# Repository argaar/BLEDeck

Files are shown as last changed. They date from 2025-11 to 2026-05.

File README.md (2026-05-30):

# BLEDeck



A custom BLE macro pad controlled by a Windows desktop application. Press a key, run a command. Switch profile, change context. Everything is driven by the app, the device is a pure peripheral.

<p align="center">
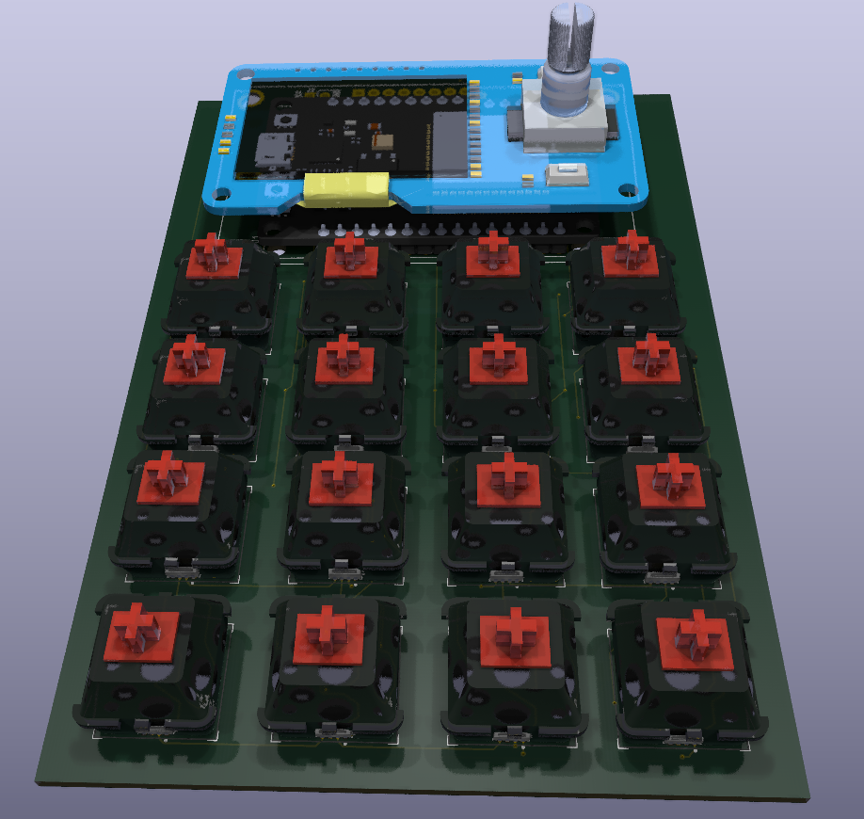
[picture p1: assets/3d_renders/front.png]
BLEDeck front render
  
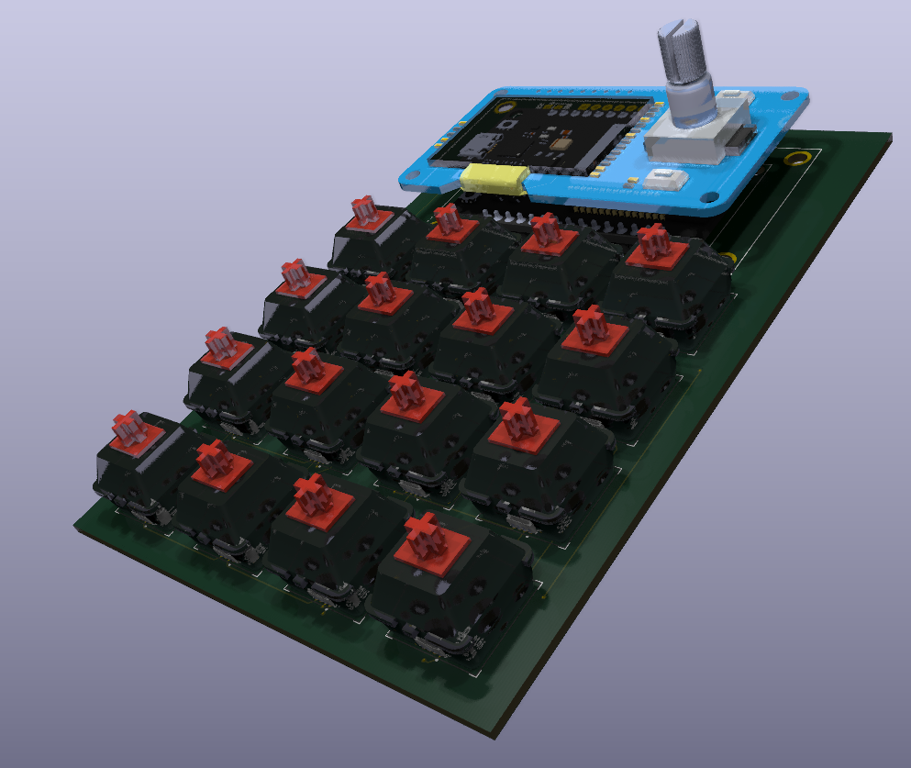
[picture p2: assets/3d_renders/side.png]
BLEDeck side render
  
</p>

---

## Overview

BLEDeck is a 4×4 mechanical keypad with per-key RGB lighting, a rotary encoder, and an OLED display, built around an ESP32. It communicates over BLE with a Windows app that maps each key to a shell command or executable. Profiles let you maintain separate key layouts for different workflows.

The device carries no persistent state. Every time the app connects, it pushes the current profile names and key colors to the device. This is by design, the app is the source of truth.

---

## Hardware

| Component | Part |
|---|---|
| MCU | ESP32 DevKitC v1 (NodeMCU-32S) |
| Keys | 16 × Gateron switches (CherryMX style) on Kailh hot-swap sockets |
| RGB | 16 × WS2812B-4020 side-emitting SMD LEDs |
| Display | SSD1306 128×64 OLED |
| Encoder | EC11 rotary encoder with push button |
| Extra buttons | CON (confirm) + BACK, mounted beside the encoder |
| Battery | Optional 1S LiPo with 15 kΩ / 4.3 kΩ voltage divider on GPIO 13 |
| PCB | Custom KiCad design, v1.1 (files under `pcb/`) |

<p align="center">
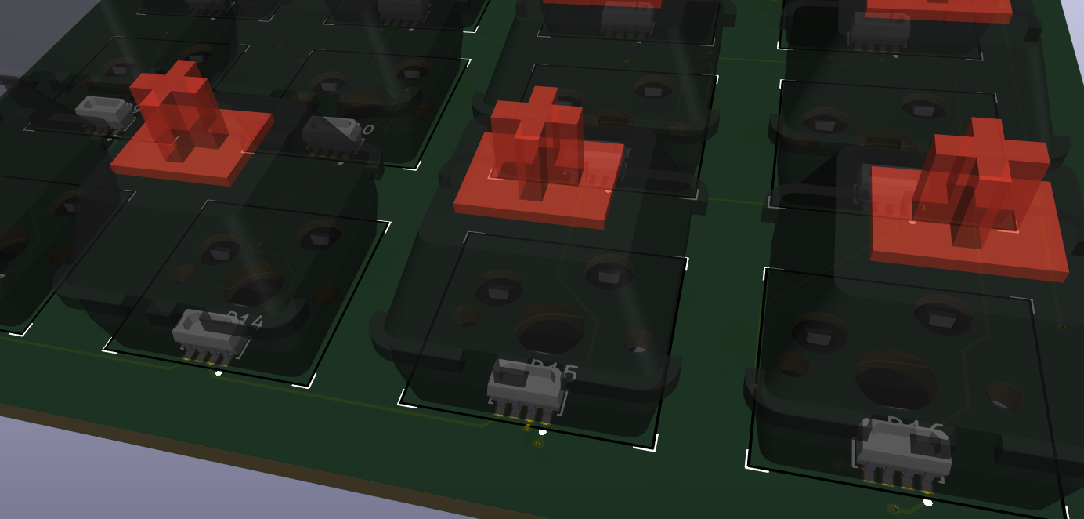
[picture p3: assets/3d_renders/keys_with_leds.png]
Keys with per-key RGB LEDs
  
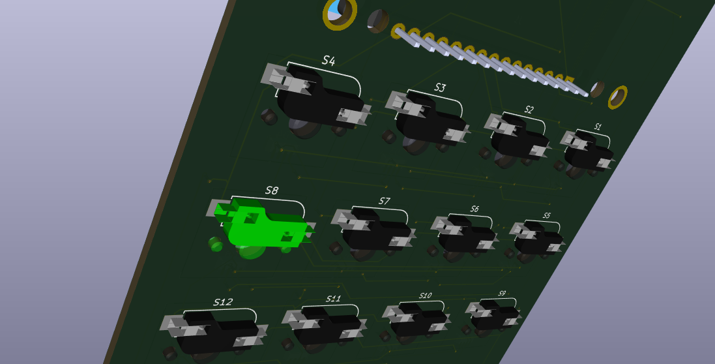
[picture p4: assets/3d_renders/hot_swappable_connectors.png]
Hot-swappable switch connectors
  
</p>

---

## Repository Layout

```
BLEDeck/
├── firmware/          PlatformIO project (ESP32 Arduino)
│   └── src/
│       ├── main.cpp            Main loop, BLE callbacks, all handlers
│       ├── configuration.h     Pin map, BLE limits, battery constants
│       ├── protocolparser.h    Binary protocol definition + packet parser
│       ├── ota_manager.h/.cpp  WiFi OTA update manager (ElegantOTA)
│       ├── menu.h              Simple OLED settings menu
│       ├── images.h            XBM splash/lock screen bitmaps
│       └── credentials.h       WiFi + OTA password (gitignored, see below)
├── windows_app/       PyQt5 desktop application
│   ├── main.py                 BLEDeck GUI, BLE lifecycle, notification dispatch
│   ├── key_button.py           KeyButton widget
│   ├── ble_protocol.py         Packet builders, parsers, opcode constants
│   ├── ble_client.py           BleakClient re-export, BLE UUIDs, simulator factory
│   ├── profile_manager.py      Load/save profiles.json
│   ├── app_settings.py         Persistent app-level settings (preferred device MAC, …)
│   ├── action_runner.py        Command/macro dispatch with re-entrancy guard
│   ├── macro_models.py         Immutable step types + JSON serialization
│   ├── macro_recorder.py       pynput-based recorder with window anchor detection
│   ├── macro_player.py         Synchronous macro playback
│   ├── macro_dialog.py         MacroDialog QDialog (record, edit, reorder, test)
│   ├── win32_utils.py          Windows API helpers (window/monitor detection)
│   └── tests/                  Pytest suite
│       ├── test_ble_protocol.py
│       ├── test_profile_manager.py
│       ├── test_action_runner.py
│       └── test_macro_models.py
├── simulator/         BLE device simulator (no hardware needed)
│   ├── __main__.py             Entry point: python -m simulator [--ble]
│   ├── _context.py             Module-level singletons (DeviceState, active client)
│   ├── device_state.py         Simulated device state
│   ├── command_handler.py      PC→Device command handler
│   ├── event_emitter.py        Device→PC event builders
│   ├── ble_server.py           Real BLE via WinRT GattServiceProvider (Mode B)
│   ├── fake_bleak_client.py    In-process loopback (Mode A)
│   ├── cli.py                  Interactive REPL
│   └── tests/                  Pytest suite
├── pcb/               KiCad schematic + layout + Gerbers
├── docs/              Protocol reference and debugging guides
│   ├── ble_protocol_reference.md
│   ├── protocol_debugging.md
│   └── hex_quick_reference.md
└── debug/
    └── protocol_decoder.py     CLI tool to decode raw BLE packets
```

---

## Firmware

Full setup and configuration details: [`firmware/README.md`](firmware/README.md)

### Features

- **BLE GATT server** - custom service with a TX (notify) and RX (write) characteristic
- **Binary protocol** - compact framed packets: `0xAA | OPCODE | LENGTH(2B) | PAYLOAD`; max payload 256 bytes
- **Profile management** - up to 10 profiles; names and current index are pushed by the app on connect
- **Rotary encoder** - cycles through profiles when the app is connected; plays an idle RGB animation when disconnected
- **Per-key RGB** - 16 WS2812B LEDs, colors set individually or all at once by the app
- **OLED display** - shows current profile name, BLE connection status, and battery percentage
- **Battery monitoring** - ADC reading every 30 s, 5-sample rolling average, reported to the app via opcode `0x85`
- **Workstation lock** - when locked by the app, the OLED dims and shows a lock icon; all key events are suppressed
- **OTA updates** - long-press the encoder push button to open the settings menu, select *OTA Update*; the device connects to WiFi (or falls back to an AP) and serves the ElegantOTA web UI
- **`OP_HELLO` / `OP_DEVICE_TELEMETRY` handshake** - on connect the app sends `OP_HELLO` with its protocol/app version, the device replies with telemetry (firmware version, uptime, free heap, BLE error count)
- **OTA HTTP auth rate-limit infrastructure** - 5 failed logins within 60 s trigger a 5-minute lockout (trigger awaits an ElegantOTA upstream hook)

### Firmware Setup

1. Install [PlatformIO](https://platformio.org/).
2. Copy `firmware/src/credentials.h.example` → `firmware/src/credentials.h` and fill in:
   ```cpp
   #define OTA_WIFI_SSID     "your_ssid"
   #define OTA_WIFI_PASSWORD "your_wifi_password"
   #define OTA_HTTP_PASSWORD "your_ota_http_password"
   ```
3. Build and flash:
   ```bash
   cd firmware
   pio run --target upload
   ```

### Build a personalized firmware via GitHub Actions (no toolchain)

Don't want to install PlatformIO? You can have GitHub build a firmware binary
with **your own** WiFi + OTA credentials baked in and email it to you. The
`Build Personalized Firmware` workflow handles it.

1. **Fork** this repository to your own GitHub account (Actions and secrets run
   under your fork, not the upstream repo).
2. In your fork, add two repository secrets under
   **Settings → Secrets and variables → Actions → New repository secret**:
   - `MAIL_USERNAME` — the Gmail address that sends the build
   - `MAIL_PASSWORD` — a Gmail [App Password](https://support.google.com/accounts/answer/185833)
     for that account (requires 2-Step Verification; your normal password will
     not work)
3. Open the **Actions** tab → **Build Personalized Firmware** →
   **Run workflow**, and fill in:
   - `wifi_ssid`, `wifi_password` — the network the device joins for OTA
   - `ota_http_password` — the password for the OTA upload page
   - `recipient_email` — where to send the finished `firmware.bin`
4. Wait for the run to finish (a few minutes). The compiled `firmware.bin`
   arrives by email; flash it to the ESP32 with ElegantOTA or `esptool`.

> **Spam note:** the email is sent from a personal Gmail account with an
> attachment, so it can land in **Spam/Junk**. If it doesn't show up in your
> inbox within a few minutes, check there and mark it *Not spam*.

> **Privacy note:** the credentials you enter are masked in the build logs and
> the generated `credentials.h` is deleted at the end of the run, but the
> finished binary still contains them and travels through Gmail. Use this for
> personal networks, not shared/sensitive ones.

---

## Windows App

Full setup and usage details: [`windows_app/README.md`](windows_app/README.md)

### Features

- Scan and connect to BLEDeck over BLE (auto-reconnect optional)
- **Per-key configuration** - label, RGBW color (with color picker + brightness slider), action
- **Two action types per key** - shell command (via `subprocess`) or recorded macro
- **Macro recorder** - capture mouse clicks and keystrokes; replay them on key press
  - Per-click window/monitor-relative coordinates: clicks are anchored to the window or monitor they were recorded on, so playback works even if windows have moved
  - Multi-monitor support: monitors indexed by left edge (0 = leftmost)
  - Edit individual steps, drag-to-reorder, delete steps, test-run from the dialog
- **Profile management** - create, rename, save, and delete profiles; stored in `profiles.json`
- **Live RGB sync** - changing a key color sends the update to the device immediately
- **Battery indicator** - displays the battery percentage reported by the device
- **System tray** - minimises to tray, double-click or single-click to restore
- On connect: pushes all profile names, then the current profile index + RGB colors
- **Rotating debug log** at `%APPDATA%\BLEDeck\logs\bledeck.log` (5 × 20 MB rotation, 100 MB cap; KEEP_ALIVE traffic filtered out)
- **Preferred device MAC pinning** + **exponential reconnect backoff** (10 s → doubles per failed attempt → 5 min cap; resets on success)
- **High-risk command-token warning** on profile load — flags commands containing tokens such as `powershell`, `cmd /c`, `iex`, `curl … | iex`, `bitsadmin`, `mshta` before they can run
- **Macro recorder auto-stop** after 60 s of idle keyboard / mouse activity

### App Setup

```bash
cd windows_app
pip install -r requirements.txt
python main.py
```

> Python 3.12 or later required. Tested on Windows 11.

### Development Without Hardware

A device simulator is included — no physical BLEDeck required.

Loopback mode (default): no Bluetooth, instant connect. Pick the row for your shell:

| Shell | Command |
|---|---|
| cmd.exe | `set BLEDECK_SIM=1 && python windows_app\main.py` |
| PowerShell  | `$env:BLEDECK_SIM=1; python windows_app\main.py` |
| Git Bash | `BLEDECK_SIM=1 python windows_app/main.py` |

Real BLE mode (two machines): simulator on Machine A, app on Machine B:

```bash
python -m simulator --ble
```

Full details: [`simulator/README.md`](simulator/README.md)

---

## BLE Protocol

Full reference: [`docs/ble_protocol_reference.md`](docs/ble_protocol_reference.md)

| Direction | Opcodes |
|---|---|
| PC → Device | `0x01` KEEP_ALIVE, `0x02` CHANGE_PROFILE, `0x03` SYNC_PROFILES, `0x04` SET_RGB_KEY, `0x05` SET_ALL_RGB_KEYS, `0x06` LOCK_DEVICE, `0x07` HELLO |
| Device → PC | `0x81` KEEP_ALIVE_REPLY, `0x82` PROFILE_CHANGED, `0x83` BUTTON_PRESSED, `0x84` KEY_PRESSED, `0x85` BATTERY_STATUS, `0x86` DEVICE_TELEMETRY |

To decode a raw packet from the log:
```bash
cd debug
python protocol_decoder.py "aa 85 00 01 48"
# or interactive:
python protocol_decoder.py
```

For advanced debugging see [`docs/protocol_debugging.md`](docs/protocol_debugging.md)
If you're interested in understanding the protocol, take a look at [`docs/hex_quick_reference.md`](docs/hex_quick_reference.md)

---

## Intended Use

BLEDeck is designed for Windows power users who want a physical shortcut pad without writing firmware macros. Key assignments live entirely in the app, change them without reflashing.

Typical profiles:
- **Dev** - open IDE, terminal, browser, run build script
- **Media** - control Spotify, OBS, volume
- **Gaming** - push-to-talk, clips, Discord mute
- **Comms** - join meeting, mute mic, share screen

The rotary encoder switches between profiles. The three encoder-side buttons (CON, BACK, PUSH) send named button events to the app, which can be mapped to any action.

---

## Limitations

- **Windows only** - the desktop app uses PyQt5, bleak, and ctypes Win32 APIs; no macOS or Linux app exists yet
- **App required** - the device does not persist colors or profile names; it resets to defaults when the app disconnects. This is intentional
- **10 profiles max, 16 keys per profile**
- **BLE range** - approximately 10 m in open space; walls reduce this
- **Battery gauge accuracy** - ±5%, based on a two-resistor voltage divider and a 5-sample average; calibrated for 1S LiPo (3.2 V – 4.2 V)
- **Macro recorder captures press events only** - release timing and mouse movement paths are not recorded

---

## PCB

Custom two-layer board designed in KiCad. Gerbers for JLCPCB are included under `pcb/`. Parts list and supplier links are in [`pcb/README.md`](pcb/README.md).

Current version: **v1.1**

---

## STLs

3D Models ready to be printed in PLA are available under `enclosure/stls` folder.

Ideally you need to assemble parts in the order:

- [PushButton.stl](enclosure/stls/PushButton.stl) (x2)
- [KeyboardLayer.stl](enclosure/stls/KeyboardLayer.stl)
- [BatteryTop.stl](enclosure/stls/BatteryTop.stl)
- [BatteryLayer.stl](enclosure/stls/BatteryLayer.stl)
- [Bottom.stl](enclosure/stls/Bottom.stl)

---

## License

Firmware and application source code are licensed under the [MIT License](LICENSE).

Hardware design files (PCB, schematics) and third-party component symbols/footprints retain their original licenses as listed in [`pcb/README.md`](pcb/README.md). The custom `oledknob.step` footprint is non-commercial use only.

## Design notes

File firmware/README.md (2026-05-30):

# BLEDeck Firmware

**Version: 1.2.5** — see [`src/version.h`](src/version.h)

ESP32 firmware for the BLEDeck macro pad. Built with PlatformIO and the Arduino framework. Acts as a BLE GATT peripheral - all logic and configuration are driven by the [Windows app](../windows_app/).

---

## Requirements

- [PlatformIO](https://platformio.org/) (CLI or VS Code extension)
- Board: **ESP32 DevKitC v1 / NodeMCU-32S**

---

## Setup

### 1. Create credentials file

The OTA credentials are not committed. Copy the example and fill it in:

```bash
cp src/credentials.h.example src/credentials.h
```

Edit `src/credentials.h`:

```cpp
#define OTA_WIFI_SSID     "your_wifi_ssid"
#define OTA_WIFI_PASSWORD "your_wifi_password"
#define OTA_HTTP_PASSWORD "your_ota_http_password"
```

### 2. Build and flash

```bash
pio run --target upload
```

Monitor serial output (115200 baud):

```bash
pio device monitor
```

### Optional build environments

`platformio.ini` defines two extra environments for diagnostics:

| Environment | Flag set | Purpose |
|---|---|---|
| `env:debug` | `-DDEBUG_SERIAL=1` | Verbose serial logging — prints every RX/TX packet, button presses, RGB updates. Default builds keep non-error prints silent. |
| `env:calibrate` | `-DCALIBRATE_BATTERY=1` | Battery-divider calibration mode. Sampling drops to every 5 s and the firmware prints both the current `BAT_CALIBRATION` value and the formula needed to retune it against a multimeter reading. |

Examples:

```bash
pio run -e debug --target upload          # Verbose logging build
pio run -e calibrate --target upload      # Calibration build
pio device monitor                        # Read the serial log
```

Switch back to the default environment by running `pio run --target upload` (or `pio run -e nodemcu-32 --target upload`).

### Native unit tests

Pure-host tests for the protocol parser and OTA rate-limit logic run on
PlatformIO's `native` env (Unity framework, no ESP32 required):

**Prerequisite:** A host C/C++ compiler. PlatformIO bundles only the
xtensa-esp32 toolchain — it does not ship a host gcc. Install one of:

| OS | Option |
|----|---|
| Windows | [w64devkit](https://github.com/skeeto/w64devkit/releases) (~80 MB zip; extract, add `bin/` to PATH) — lightest |
| Windows | `scoop install gcc` or `choco install mingw` |
| Linux | usually pre-installed; otherwise `sudo apt install build-essential` (or distro equivalent) |
| macOS | `xcode-select --install` |

Verify with `gcc --version` before running the command below.

```bash
pio test -e native
```

Tests live under `firmware/test/`. Add new native tests as
`test/<test_name>/test_main.cpp` — PlatformIO discovers each subdirectory
automatically.

---

## Pin Map

| Function | GPIO |
|---|---|
| OLED SDA | 21 |
| OLED SCL | 22 |
| Encoder A | 35 |
| Encoder B | 34 |
| Button CON | 36 |
| Button BACK | 39 |
| Button PUSH | 27 |
| Keypad rows | 32, 33, 25, 26 |
| Keypad cols | 5, 18, 19, 23 |
| RGB data | 14 |
| Battery ADC | 13 |

**Power & ground:** OLED VCC = 3.3 V. Encoder PUSH input (GPIO 27) is wired to the EC11 SW pin and shares the encoder common GND.

---

## Features

### BLE
- GATT server advertising as `BLEDeck`
- Custom service UUID `4FAFC201-...`
- TX characteristic (notify) for device → app events
- RX characteristic (write) for app → device commands
- TX power set to maximum (+9 dBm) for range
- Auto-restarts advertising on disconnect

### Keypad
- 4×4 matrix, keys labelled `0`–`9`, `A`–`F`
- Each keypress sends `OP_KEY_PRESSED` with the current profile index and key character

### Rotary encoder + buttons
- Turning the encoder cycles through profiles (wraps around)
- **CON** and **BACK** send `OP_BUTTON_PRESSED` with the button name
- **PUSH** short-press sends `OP_BUTTON_PRESSED`
- **PUSH** long-press (≥ 1500 ms) opens the settings menu

### RGB LEDs
- 16 × WS2812B-4020 controlled via NeoPixelBus
- App sets colors per-key (`OP_SET_RGB_KEY`) or all at once (`OP_SET_ALL_RGB_KEYS`)
- Idle animation (rotating rainbow) plays when no app is connected
- Colors reset to defaults on disconnect - the app re-applies them on every connect

### OLED display
- Shows current profile name, BLE connection status, and battery percentage
- Displays a lock icon when the workstation is locked

### Battery monitoring
- ADC reading on GPIO 13 every 30 s (5-sample rolling average)
- Voltage divider: 15 kΩ (top) / 4.3 kΩ (bottom), calibrated for 1S LiPo (3.2 V – 4.2 V). `BAT_R1 = 15000` and `BAT_R2 = 4300` in `configuration.h` match the soldered PCB (the schematic Value fields are wrong — trust the constants, not the schematic).
- Reports percentage to the app via `OP_BATTERY_STATUS (0x85)` immediately on connect and after each reading
- `0xFF` is sent when no battery is detected (USB-only)

#### Battery calibration

The easiest way to calibrate is to flash the `env:calibrate` build. It prints both the current `BAT_CALIBRATION` constant and the value you need to paste back into `configuration.h`, sampling every 5 seconds.

GPIO 13 is on ADC2, which over-reads versus the true input voltage. `BAT_CALIBRATION` in `configuration.h` (currently `0.3607`) absorbs that drift. To tune it on a specific board:

1. Connect over USB and open the serial monitor (115200 baud). The firmware now prints a battery line **unconditionally every 30 s**:
   ```
   [BAT] adc=XXXX mV  vbat=YYYY mV  pct=ZZ
   ```
2. Probe the battery terminals with a multimeter at the same moment and note the real voltage (e.g. `3987 mV`).
3. Recompute the constant:
   ```
   BAT_CALIBRATION_new = multimeter_mV / vbat_mV * BAT_CALIBRATION_current
   ```
   For example, if `vbat = 3700 mV`, multimeter reads `3987 mV` and current `BAT_CALIBRATION = 0.3607`:
   `0.3607 * (3987 / 3700) ≈ 0.3887`.
4. Update `BAT_CALIBRATION` in `configuration.h`, reflash, and verify. A two-point measurement (e.g. ~3.4 V and ~4.1 V) is enough for ±1 % accuracy across the full pack range.

### Workstation lock
- `OP_LOCK_DEVICE (0x06)` from the app locks/unlocks the device
- When locked: OLED dims, lock icon displayed, all key/encoder events suppressed

### OTA update
1. Long-press the PUSH button to open the settings menu
2. Select **OTA Update** - BLE is shut down, WiFi starts
3. Connect a browser to the device IP (or to `BLEDeck-OTA` AP if WiFi credentials fail). The AP fallback uses a **randomized 12-character password** printed on the OLED and over serial.
4. Log in to the ElegantOTA web interface using the `OTA_HTTP_PASSWORD` you set in `credentials.h` and upload a new `.bin`
5. Device restarts automatically. To cancel an in-progress OTA session, **hold BACK for at least 1000 ms** (a brief tap is ignored, so an accidental press doesn't abort a flash).
6. OTA session times out after 5 minutes if no upload is started

### Protocol handshake & telemetry

On every BLE connect, the app sends `OP_HELLO` (0x07) with its app version and the negotiated `PROTOCOL_VERSION`. The firmware replies with `OP_DEVICE_TELEMETRY` (0x86) carrying the firmware version, current uptime, last-reset reason (`esp_reset_reason()`), free heap, and a running BLE-error counter incremented on every malformed packet, send failure, or oversize payload. Mismatched protocol versions surface a CRITICAL warning in the app's log and a status-bar message.

### OTA rate-limit

The OTA HTTP endpoint tracks failed authentication attempts in a small ring buffer. **Five failures within 60 s trigger a 5-minute lockout**, during which all incoming HTTP traffic is dropped (`server_->handleClient()` is skipped). The lockout counter infrastructure is fully wired; ElegantOTA 3.1.7 does not currently expose an auth-failure callback, so the trigger awaits either an upstream hook or a future self-hosted route handler — see the TODO at the top of `OtaManager::loop()`.

### Task watchdog

The ESP32 Arduino framework feeds the IDLE task watchdog automatically as long as `loop()` returns within the configured timeout (default 5 s). BLE callbacks (`onConnect`, `onDisconnect`, RX characteristic write) run on the NimBLE host task — keep them to flag-flipping plus simple state updates; never call `delay()`, I²C, or SPI. OTA mode shuts BLE down before WiFi starts, so the BLE task is dormant during ElegantOTA serving. See the comment block above `setup()` in `main.cpp`.

---

## Source Files

| File | Purpose |
|---|---|
| `main.cpp` | Setup, main loop, BLE callbacks, all packet handlers |
| `configuration.h` | Pin definitions, BLE limits, battery constants |
| `protocolparser.h` | Protocol definition (all opcodes), binary packet parser |
| `ota_manager.h/.cpp` | WiFi connection, ElegantOTA lifecycle, AP fallback |
| `menu.h` | Minimal OLED scrollable menu |
| `images.h` | XBM bitmaps (splash screen, lock icon) |
| `version.h` | Firmware version constants (`FIRMWARE_VERSION`, `_MAJOR/_MINOR/_PATCH`) |
| `credentials.h` | WiFi SSID/password + OTA password (gitignored) |

---

## Configuration Constants (`configuration.h`)

| Constant | Default | Description |
|---|---|---|
| `MAX_BLE_PAYLOAD_LEN` | 256 | Parser hard limit (matches `MAX_PAYLOAD_LEN` in protocol) |
| `MENU_LONG_PRESS_MS` | 1500 | Hold duration to open settings menu |
| `OTA_TIMEOUT_MS` | 300 000 | OTA idle timeout before auto-restart (ms) |
| `BAT_INTERVAL_MS` | 30 000 | Battery ADC read interval (ms) |
| `BAT_MIN_V` | 3200 | Minimum LiPo voltage mapped to 0% (mV) |
| `BAT_MAX_V` | 4200 | Maximum LiPo voltage mapped to 100% (mV) |
| `BAT_NUM_READ` | 5 | Rolling average window for ADC readings |

To disable battery support entirely, comment out `#define USE_BATTERY` in `configuration.h`.

---

## Dependencies

| Library | Version | Purpose |
|---|---|---|
| chris--a/Keypad | ^3.1.1 | 4×4 matrix keypad scan |
| maffooclock/ESP32RotaryEncoder | ^1.1.2 | Interrupt-driven rotary encoder |
| thomasfredericks/Bounce2 | ^2.72 | Button debouncing |
| ThingPulse/esp8266-oled-ssd1306 | 4.6.1 | SSD1306 OLED driver |
| makuna/NeoPixelBus | ^2.8.4 | WS2812B RGB LED control |
| rlogiacco/CircularBuffer | ^1.4.0 | Rolling ADC average buffer |
| ayushsharma82/ElegantOTA | ^3.1.7 | Web-based OTA update UI |

---

## Protocol

See [`../docs/ble_protocol_reference.md`](../docs/ble_protocol_reference.md) for the full binary protocol specification.

Quick opcode reference:

| Opcode | Direction | Name |
|---|---|---|
| `0x01` | App → Device | KEEP_ALIVE |
| `0x02` | App → Device | CHANGE_PROFILE |
| `0x03` | App → Device | SYNC_PROFILES |
| `0x04` | App → Device | SET_RGB_KEY |
| `0x05` | App → Device | SET_ALL_RGB_KEYS |
| `0x06` | App → Device | LOCK_DEVICE |
| `0x07` | App → Device | HELLO |
| `0x81` | Device → App | KEEP_ALIVE_REPLY |
| `0x82` | Device → App | PROFILE_CHANGED |
| `0x83` | Device → App | BUTTON_PRESSED |
| `0x84` | Device → App | KEY_PRESSED |
| `0x85` | Device → App | BATTERY_STATUS |
| `0x86` | Device → App | DEVICE_TELEMETRY |

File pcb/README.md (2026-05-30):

# Parts list

### LED RGB WS2812b SMD 4020
https://jlcpcb.com/partdetail/Worldsemi-WS2812B4020/C965557

### Through Hole Resistor 2.2*6.5 250mW (15k + 4.3k)
Battery voltage divider on GPIO 13 (R1=15k top to BAT+, R2=4.3k bottom to GND).
https://jlcpcb.com/partdetail/59662-MFR0W4F1502A50/C58617
https://jlcpcb.com/partdetail/NTEElectronics-QW243/C6262373

### ESP32 DevKitC v1
https://lastminuteengineers.com/esp32-pinout-reference/
https://www.adrirobot.it/modulo-esp32-devkit-v1-con-wifi-e-bluetooth-ble/

### OLED (SSD1306) + Knob (EC11 rotary encoder)
https://it.aliexpress.com/item/1005009186762942.html

### Gateron Switches (CherryMX Style)
https://keychron.it/products/gateron-g-pro-3-0-switch?variant=51681846395247
https://it.aliexpress.com/item/1005006376024657.html

### Switch Transparent Cover
https://it.aliexpress.com/item/1005006821410180.html

### Kahil Hot swappable sockets
https://splitkb.com/products/kailh-hotswap-sockets
https://www.amazon.it/dp/B0DJKTNDHF
https://it.aliexpress.com/item/1005004654079817.html

### Adesive TPU Pads
https://it.aliexpress.com/item/1005006390636772.html

# Resources licenses

### Symbols

- ESP32-DEVKIT-V1.kicad_sym - https://www.snapeda.com/parts/ESP32-DEVKIT-V1/Do+it/view-part/ - CC-BY-SA
- PG151101S11.kicad_sym - https://www.snapeda.com/parts/PG151101S11/Kailh/view-part/ - CC-BY-SA
- WS2812B-4020.kicad_sym - https://www.snapeda.com/parts/WS2812B-4020/Worldsemi/view-part/ - CC-BY-SA

### Footprints

- MODULE_ESP32_DEVKIT_V1.kicad_mod - https://www.snapeda.com/parts/ESP32-DEVKIT-V1/Do+it/view-part/ - CC-BY-SA
- Kailh_socket_MX.kicad_mod - https://github.com/daprice/keyswitches.pretty - CC-BY-SA 4
- oled_rotary.kicad_mod - Custom Made under MIT License
- PinHeader_1x02_P2.54mm_Vertical.kicad_mod - https://gitlab.com/kicad/libraries/kicad-footprints/ - CC-BY-SA 4
- WS2812B-4020.kicad_mod - https://www.snapeda.com/parts/WS2812B-4020/Worldsemi/view-part/ - CC-BY-SA

### 3D Models

- CherryMX Switch.step - https://github.com/foostan/kbd - MIT
- ESP32-DEVKIT-V1.step - https://www.snapeda.com/parts/ESP32-DEVKIT-V1/Do+it/view-part/ - CC-BY-SA
- kailh_hotswap_socket.step - https://www.snapeda.com/parts/PG151101S11/Kailh/view-part/ - CC-BY-SA
- oledknob.step - https://grabcad.com/library/1-3-oled-ec11-1 - No commercial use
- WS2812B-4020--3DModel-STEP-269445.STEP - https://www.snapeda.com/parts/WS2812B-4020/Worldsemi/view-part/ - CC-BY-SA

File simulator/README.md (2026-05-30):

# BLEDeck Simulator

Software emulator for the BLEDeck hardware device. Lets developers work on the Windows app without owning a physical device.

Two modes:

| Mode | What it does | When to use |
|---|---|---|
| **Mode A — Loopback** (default) | In-process fake BLE client. No radio needed. | Daily development, CI, no Bluetooth hardware |
| **Mode B — Real BLE** (`--ble`) | Advertises via WinRT GattServiceProvider. App on a second machine connects normally. | Cross-machine BLE integration testing |

---

## Setup

All commands run from the **project root** (`BLEDeck/`), not from inside `simulator/`.

```bash
# Reuse the windows_app venv (recommended — bleak is already installed there)
windows_app\env\Scripts\activate      # Windows
# source windows_app/env/bin/activate # Linux / macOS

# Or create a dedicated venv
python -m venv simulator/env
simulator\env\Scripts\activate
pip install -r simulator/requirements.txt   # pinned bleak==3.0.2 (+ winrt-* for Mode B) + pytest
```

Mode B (real BLE) uses the WinRT `GattServiceProvider` API via the `winrt-*` packages that `bleak` installs automatically. No separate BLE server library is needed.

Mode A (loopback) needs no extra packages beyond `windows_app/` dependencies.

---

## Mode A — Loopback (default)

Set the environment variable `BLEDECK_SIM=1` and run the app. The app uses `FakeBleakClient` — no radio, instant connect. The simulator CLI starts automatically inside the same process.

| Shell | Command |
|---|---|
| cmd.exe | `set BLEDECK_SIM=1 && python windows_app\main.py` |
| PowerShell  | `$env:BLEDECK_SIM=1; python windows_app\main.py` |
| Git Bash | `BLEDECK_SIM=1 python windows_app/main.py` |

Pick the row matching your shell. Mac/Linux users export the env var the standard way (Git Bash row applies).

No separate simulator process needed. The `sim>` prompt appears in the same terminal.

Alternatively, run the simulator standalone (CLI only — useful for scripting events without launching the full GUI):

```bash
python -m simulator
```

Then in another terminal: `BLEDECK_SIM=1 python windows_app/main.py`. The CLI in the first terminal drives the app.

---

## Mode B — Real BLE (`--ble`)

Runs a GATT server using the WinRT `GattServiceProvider` API. Requires two machines: simulator on Machine A, app on Machine B.

> ⚠️ **Two machines required on Windows.** The Windows BLE stack does not
> allow same-machine self-connection — running `python -m simulator --ble`
> AND `python windows_app/main.py` on the same PC will hang forever with no
> error. The simulator now prints this warning on startup; install the app
> on a second machine to connect.

```bash
python -m simulator --ble
```

Then launch the Windows app normally on another machine (`python windows_app/main.py`). It scans for service UUID `4FAFC201-…`, connects, and behaves identically to a physical device.

The CLI prompt appears after the server starts:

```
INFO: [BLE] Advertising (service UUID: 4FAFC201-...)
sim>
```

### Platform notes

| Platform | Status |
|---|---|
| Windows | Primary target. Uses WinRT `GattServiceProvider` — no admin required. Device name is not set in advertisement (WinRT limitation); app connects via service UUID automatically. |
| Linux / macOS | Not supported for Mode B. Use Mode A (loopback) instead. |

---

## CLI Commands (both modes)

```
sim> battery <n>          Send BATTERY_STATUS  (0–100, or -1 for no-battery/USB)
sim> press <idx> <char>   Send KEY_PRESSED     (profile index 0-based, single char)
sim> button <name>        Send BUTTON_PRESSED  (current profile, button name)
sim> profile <idx>        Send PROFILE_CHANGED and update local state (0-based)
sim> state                Print current device state
sim> help                 Show this help
sim> quit                 Exit
```

Examples:

```
sim> battery 72           # device reports 72 % battery
sim> press 0 A            # profile 0, key char 'A' pressed
sim> button macro1        # named button pressed on current profile
sim> profile 2            # switch to profile index 2
sim> state
  profile_index : 2
  profiles      : {1: 'Default', 2: 'Work'}
  locked        : False
  battery       : 72%
  rgb_matrix    : 3/16 keys lit
```

> The simulator automatically replies with `OP_DEVICE_TELEMETRY` whenever it receives an `OP_HELLO` from the app — no manual CLI invocation needed.

---

## File Structure

```
simulator/
  __init__.py          sys.path shim — adds windows_app/ so ble_protocol.py is importable
  __main__.py          Entry point: python -m simulator [--ble]
  device_state.py      DeviceState dataclass (profiles, RGB matrix, lock, battery)
  command_handler.py   Parses PC→Device packets, mutates state, returns response bytes
  event_emitter.py     Builds Device→PC event packets
  ble_server.py        WinRT GattServiceProvider GATT server (Mode B)
  fake_bleak_client.py FakeBleakClient + FakeBleakScanner (Mode A)
  _context.py          Module-level singletons shared between app and CLI in Mode A
  cli.py               Async REPL used by both modes
  requirements.txt
  tests/
    conftest.py
    test_command_handler.py   every opcode + edge cases
    test_event_emitter.py     round-trip packet assertions
    test_fake_client.py       FakeBleakClient API surface
```

`command_handler.py` and `event_emitter.py` import `ble_protocol.py` directly from `windows_app/` — single source of truth for opcodes and packet layout.

---

## Running Tests

```bash
# from repo root (uses windows_app venv)
python -m pytest simulator/tests/ -v
```

No external dependencies beyond `pytest`.

---

## How It Works

### Mode B (real BLE)

```
[simulator process]
  BLEServer (WinRT GattServiceProvider)
    ├── advertises service UUID 4FAFC201-... (connectable + discoverable)
    ├── RX write → command_handler.handle() → state mutation
    │   KEEP_ALIVE write → KEEP_ALIVE_REPLY notification sent back
    └── TX notify ← event_emitter packets triggered by CLI commands
  CLI (asyncio REPL)
    └── "battery 80" → emit.battery_status(80) → BLEServer.send_event()

[app process — unmodified]
  BleakScanner.discover(service_uuids=[...]) → finds simulated device
  BleakClient.connect() → GATT connection established
  RX write OP_HELLO → command_handler stores app version → reply OP_DEVICE_TELEMETRY via event_emitter
  handle_notification() ← TX notifications from simulator
```

### Mode A (loopback)

```
[single process — app + simulator]
  BLEDECK_SIM=1 → ble_client.py returns FakeBleakClient
  FakeBleakClient.connect()          → immediate success
  RX write OP_HELLO → command_handler stores app version → reply OP_DEVICE_TELEMETRY via event_emitter
  FakeBleakClient.write_gatt_char()  → command_handler.handle()
  FakeBleakClient.start_notify()     → stores handle_notification callback
  FakeBleakClient.push_event()       → calls handle_notification directly
  CLI (_run_sim_cli asyncio task)
    └── "press 0 A" → emit.key_pressed(0,'A') → push_event()
```

---

## Protocol Reference

[`docs/ble_protocol_reference.md`](../docs/ble_protocol_reference.md) — full opcode table and payload layouts.

When a new opcode is added to the protocol, update `command_handler.py` or `event_emitter.py` alongside `firmware/`, `windows_app/ble_protocol.py`, and the docs.

---

## Hardening notes

Recent robustness changes worth knowing about when reading or extending the simulator:

- **CHANGE_PROFILE stores the profile name.** The handler now persists the name carried by `OP_CHANGE_PROFILE` (it was previously parsed and dropped), matching firmware behaviour.
- **Malformed and oversized packets are dropped silently.** Anything that fails framing or exceeds the 256-byte payload cap is logged at DEBUG level and ignored — the simulator does not crash on garbage input.
- **CLI input validation.** `battery`, `press`, and `profile` validate their arguments before emitting any packet (range checks, single-character keys, numeric profile indices). Invalid input prints an error and emits nothing.
- **`_context.reset_state()`** clears the shared `DeviceState` / client singletons between tests. The pytest suite uses it for isolation; reach for it in new fixtures.
- **`bleak==3.0.2` pinned** in `requirements.txt` together with the explicit `winrt-*` sub-packages used by Mode B, so the WinRT GATT server build is reproducible.
- v0.1.2: `OP_HELLO` (0x07) handler stores the app version and replies with `OP_DEVICE_TELEMETRY` (0x86); telemetry payload is fully synthetic (zero uptime, zero heap) — it exists for app-side handshake testing

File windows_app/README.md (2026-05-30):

# BLEDeck Windows App

PyQt5 desktop application for the BLEDeck macro pad.
Connects over BLE, manages profiles, assigns shell commands or recorded macros to keys, and syncs colors to the device.

---

## Features

- **Rotating debug log** at `%APPDATA%\BLEDeck\logs\bledeck.log` — 5 × 20 MB rotation (100 MB cap); KEEP_ALIVE traffic filtered out; opens cleanly in any text editor
- **Preferred device MAC pinning** — first MAC connected is persisted in `%APPDATA%\BLEDeck\app_settings.json` and preferred on every scan thereafter; supports multi-BLEDeck environments
- **Exponential reconnect backoff** — auto-reconnect starts at 10 s and doubles per failed attempt up to a 5 min cap; resets to 10 s on the first successful connect
- **Workstation-lock subscription** — uses `WTSRegisterSessionNotification` for sub-50 ms lock detection on physical Windows; falls back to a 2.5 s poll on virtualized desktops
- **High-risk command warning** — profile-file load surfaces a `QMessageBox.warning` listing any commands containing tokens such as `powershell`, `cmd /c`, `iex`, `curl … | iex`, `bitsadmin`, `mshta` — review before pressing the matching device key
- **Macro recorder auto-stop** — recording sessions auto-terminate after 60 s of idle keyboard / mouse activity to limit accidental capture
- **Protocol handshake** — sends `OP_HELLO` on connect; logs `OP_DEVICE_TELEMETRY` reply (firmware version, uptime, free heap, BLE error count); CRITICAL warning if `PROTOCOL_VERSION` mismatches

---

## Requirements

- Windows 10 or 11
- Python 3.12 or later
- Bluetooth adapter with BLE support

> **Windows only.** This app links against Win32 APIs through `ctypes` (workstation-lock detection, multi-monitor enumeration) and PyQt5 system tray integration that targets the Windows shell. macOS and Linux are not supported and `build.bat` will not run on those platforms.

---

## Setup

```bash
cd windows_app
pip install -r requirements.txt        # runtime
pip install -r requirements-dev.txt    # tests (optional)
python main.py
```

> A virtual environment is recommended:
> ```bash
> python -m venv env
> env\Scripts\activate
> pip install -r requirements.txt
> python main.py
> ```

> For development (running the test suite), use `setup-dev.bat` from an activated venv — it installs both `requirements.txt` and `requirements-dev.txt`, then runs `pytest` to verify the environment.

### Running Tests

Install dev dependencies first (`pytest` lives in `requirements-dev.txt`, not `requirements.txt`):

```bash
pip install -r requirements-dev.txt
python -m pytest tests/
```

---

## Development Without Hardware

A software simulator is available in [`simulator/`](../simulator/README.md). It emulates the BLEDeck device so the app can be developed and tested without a physical device.

**Quick start — loopback mode (no Bluetooth needed):**

```bash
set BLEDECK_SIM=1
python main.py
```

The app connects instantly to a fake in-process device. A `sim>` CLI prompt appears in the terminal — use it to trigger button presses, battery updates, and profile changes.

**Real BLE mode** (requires two machines — Windows does not support BLE self-connection):

```bash
# Machine A — start the simulator
python -m simulator --ble

# Machine B — run the app normally
python windows_app/main.py
```

See [`simulator/README.md`](../simulator/README.md) for full details and CLI command reference.

---

## Building a Standalone Executable

`build.bat` is a Windows batch script and only runs on Windows. There is no macOS / Linux equivalent.

Produces a self-contained `dist\BLEDeck\` folder that runs on any Windows 10/11 machine without Python or a virtualenv.

```bash
cd windows_app
pip install -r requirements-build.txt   # installs PyInstaller
build.bat
```

Output:

```
dist\BLEDeck\
├── BLEDeck.exe      ← launch this
├── icon.ico
├── PyQt5\
├── _internal\       ← bundled Python runtime + dependencies
└── ...
```

Move the entire `dist\BLEDeck\` folder anywhere and run `BLEDeck.exe`. Profiles are stored in `%APPDATA%\BLEDeck\profiles.json` (created on first run), independent of where the exe lives.

| File | Purpose |
|---|---|
| `bledeck.spec` | PyInstaller spec — controls what gets bundled and how |
| `build.bat` | One-click build script; cleans previous output before building |
| `requirements-build.txt` | Build-time dependency (`pyinstaller>=6.0`; not needed at runtime) |

> **Note:** `build/` and `dist/` are gitignored. Only commit `bledeck.spec` and `build.bat`.

---

## Usage

### Connecting

1. Power on the BLEDeck device.
2. Click **Connect** - the app scans for a device advertising as `BLEDeck` and connects automatically.
3. On connect the app: sends a keep-alive ping, syncs all profile names to the device, then pushes the current profile index and RGB key colors.
4. Enable **Auto-reconnect** to have the app reconnect automatically if the connection drops.

### Profiles

- Use the **Profile** dropdown to switch between profiles.
- Click **New Profile** to create an empty profile.
- Edit the name in the text field, then click **Save Profile**.
- Click **Delete Profile** to remove the current profile (at least one profile must remain).

Switching profiles in the app sends the new profile data to the device. Turning the encoder on the device also switches profiles and notifies the app.

### Keys

The 4×4 grid has two behaviors depending on the active mode (Mode menu):

- **Pad mode** (default) — clicking a key immediately executes its assigned action (command or macro).
- **Edit mode** — clicking a key selects it for configuration. The action panel on the right updates to show that key's settings.

To configure a key, switch to Edit mode first:

1. Click a key button to select it.
2. Set a **Label** - shown on the button in the app.
3. Set a **Color** - enter `R,G,B,Brightness%` directly (e.g. `255,0,0,70`) or use **Pick Color** and the brightness slider. The LED on the device updates immediately.
4. Choose an **Action Type**:
   - **Command** - any shell command or executable path (e.g. `notepad.exe`, `calc.exe`, `"C:\my app\tool.exe"`, `cmd /c echo hello`). Use **Browse** to pick an `.exe`.
   - **Macro** - a recorded sequence of mouse clicks and keystrokes. Click **Edit Macro** to open the macro editor.
5. Click **Save Profile** to persist the configuration.

When a key is pressed on the physical device, the app always executes the assigned command or macro regardless of mode. Command actions and macros run in worker threads, so the GUI never freezes while a long-running command launches.

### Macro Editor

Open the macro editor via **Edit Macro** on any key configured as Macro type.

- **Record** - starts recording. Click targets and type keys; each click and keystroke is captured as a step (mouse movement between clicks is not recorded). Press **Esc** to stop. Recording also auto-stops after 60 s of no input.
- **Stop** - stops an active recording.
- **Test Run** - plays back the current macro immediately (from a background thread).
- **Edit Step** - double-click a step or select it and click Edit Step to change its values (coordinates, key, wait duration, anchor window, etc.).
- **Delete Step** - removes the selected step.
- **Clear** - removes all steps.
- Steps can be **drag-reordered** inside the list.

#### Coordinate anchoring

Mouse clicks are recorded with window-relative or monitor-relative coordinates so playback works even if windows have moved:

| Anchor | Meaning |
|---|---|
| `window:<title>` | Relative to the top-left corner of the named window (re-located at playback time) |
| `monitor:<N>` | Relative to the top-left of monitor N (0 = leftmost) — used for desktop/taskbar clicks |
| `abs` | Absolute screen coordinates |

Multi-monitor setups are supported; monitors are indexed by left edge (0 = leftmost).

### Battery

The battery percentage is shown in the top panel next to the connection status. It updates every ~30 seconds while connected. Shows `USB` when no battery is detected.

### Minimize to Tray

Closing or minimising the window hides it to the system tray. Double-click or single-click the tray icon to restore it. Right-click for **Open** / **Quit**.

---

## File Structure

| File | Purpose |
|---|---|
| `main.py` | `BLEDeckGUI` - main window, BLE lifecycle, notification dispatch, action dispatch |
| `__version__.py` | App metadata (name, version, authors, GitHub URL) used by the About dialog |
| `key_button.py` | `KeyButton(QPushButton)` - individual key widget with color and label state |
| `ble_protocol.py` | Packet builders, parsers, all opcode constants |
| `ble_client.py` | BleakClient/BleakScanner re-export, BLE UUIDs (incl. SERVICE_UUID); returns fake implementations when `BLEDECK_SIM=1` |
| `profile_manager.py` | Load/save `profiles.json` |
| `app_settings.py` | Persistent app-level settings — preferred device MAC, etc. |
| `action_runner.py` | Dispatches commands or macros; per-key re-entrancy guard |
| `macro_models.py` | Immutable step types (`ClickStep`, `KeyStep`, `SleepStep`); JSON serialization |
| `macro_recorder.py` | pynput-based recorder; per-click window/monitor anchor detection |
| `macro_player.py` | Synchronous macro playback; anchor resolution at play time |
| `macro_dialog.py` | `MacroDialog` QDialog - record, edit, reorder, test macro steps |
| `win32_utils.py` | Windows API helpers - window/monitor detection via ctypes |
| `manual.md` | In-app user manual (Help → Manual) |
| `requirements.txt` | Runtime dependencies |
| `requirements-dev.txt` | Test/dev dependencies (`pytest`) |
| `tests/` | Pytest suite - `test_ble_protocol.py`, `test_profile_manager.py`, `test_action_runner.py`, `test_macro_models.py` |
| `profiles.json` | Stored in `%APPDATA%\BLEDeck\`, not in this folder; created on first run |

---

## profiles.json

Profiles are stored in `%APPDATA%\BLEDeck\profiles.json` (created automatically on first run). Format:

```json
[
  {
    "name": "Default",
    "keys": {
      "0": { "label": "Notepad", "color": "100,150,255,70", "action_type": "command", "command": "notepad.exe" },
      "1": { "label": "Calc",    "color": "255,100,100,70", "action_type": "command", "command": "calc.exe" },
      "2": {
        "label": "Macro",
        "color": "0,200,100,70",
        "action_type": "macro",
        "macro": [
          { "type": "sleep", "duration_ms": 500 },
          { "type": "key", "key": "c", "modifiers": ["ctrl"] },
          { "type": "click", "x": 120, "y": 45, "button": "left", "relative_to": "window:Notepad" }
        ]
      }
    }
  }
]
```

Keys with no command and no macro steps are not saved. Color format is `R,G,B,Brightness%` where brightness is `0–100`.

### Schema v1 (since v0.2.2)

New saves wrap the list in a versioned envelope:

```json
{
  "version": 1,
  "profiles": [ /* same profile objects as above */ ]
}
```

- **Backward compatible** — legacy bare-list files still load fine. The next save migrates them to the v1 envelope.
- **Corruption recovery** — if `profiles.json` fails to parse, the file is renamed to `profiles.corrupt.json` and the default profiles are restored, so the app always starts.
- **Storage fallbacks** — the default location is `%APPDATA%\BLEDeck\`. If that directory cannot be created, the app falls back to `~/.bledeck`, then to the system temp directory.

### Macro step types

| Type | Fields |
|---|---|
| `sleep` | `duration_ms` |
| `key` | `key` (string), `modifiers` (array of `"ctrl"`, `"shift"`, `"alt"`, `"win"`) |
| `click` | `x`, `y`, `button` (`"left"/"right"/"middle"`), `relative_to` (anchor string) |

---

## BLE Protocol

The app communicates with the device using a custom binary protocol. See [`../docs/ble_protocol_reference.md`](../docs/ble_protocol_reference.md) for the full specification.

All packet construction and parsing is in `ble_protocol.py`. To decode a raw packet from the debug log:

```bash
cd ../debug
python protocol_decoder.py "aa 85 00 01 48"
```

### Handled incoming opcodes

| Opcode | Event | Action |
|---|---|---|
| `0x81` | KEEP_ALIVE_REPLY | Logs pong, updates connection health timestamp |
| `0x82` | PROFILE_CHANGED | Syncs app profile to match device; sends new RGB colors back |
| `0x83` | BUTTON_PRESSED | Logs button name and profile index |
| `0x84` | KEY_PRESSED | Executes the configured command for that key and profile |
| `0x85` | BATTERY_STATUS | Updates battery label in the UI |
| `0x86` | DEVICE_TELEMETRY | Logs firmware version + uptime + free heap + BLE error count; flags protocol version mismatch |

---

## Limitations

- **Windows only** - uses PyQt5, bleak, and ctypes Win32 APIs; no macOS or Linux support
- **10 profiles max, 16 keys per profile** - protocol limit
- **Macro recorder captures press events only** - release timing and mouse movement paths are not recorded

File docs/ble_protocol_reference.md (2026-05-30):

# BLE Binary Protocol Reference

This document defines the binary communication protocol used between the Python host application and the Arduino-based peripheral device over BLE. It includes packet structure, opcodes, payload formats, and usage notes.

---

# 1. Overview
The protocol is designed to be compact, binary, and easy to parse on resource-limited devices. It uses a framed packet format with a fixed header and variable payload. Communication is unidirectional per opcode group:

- **0x01–0x7F** → Python **commands** sent to Arduino
- **0x80–0xFF** → Arduino **events** sent to Python

This version of the protocol uses **no acknowledgments**, as BLE handles transport-level reliability.

## 1.1 Pairing & Encryption

Both GATT characteristics require an encrypted, MITM-authenticated link:

- TX (notify) — `ESP_GATT_PERM_READ_ENC_MITM`
- RX (write)  — `ESP_GATT_PERM_WRITE_ENC_MITM`

Pairing flow on first connect:

1. Host (Windows app) initiates pairing through the OS BLE stack.
2. Device displays a 6-digit passkey on its OLED.
3. User types the passkey into the OS pairing prompt.
4. Bond is stored in NVS and reused on subsequent connects.

Without an active bond, GATT writes are rejected by the controller before the application layer sees them. This blocks unauthenticated centrals from sending `LOCK_DEVICE`, `CHANGE_PROFILE`, or RGB commands.

## 1.2 Transport

| Item | Value |
|---|---|
| Device name | `BLEDeck` |
| Service UUID | `4FAFC201-1FB5-459E-8FCC-C5C9C331914B` |
| TX characteristic (Device → PC, NOTIFY) | `BEB5483E-36E1-4688-B7F5-EA07361B26A8` |
| RX characteristic (PC → Device, WRITE)  | `EAB5483E-36E1-4688-B7F5-EA07361B26A9` |

TX uses notify (device pushes events). RX uses write-without-response (PC pushes commands).

---

# 2. Packet Structure
All packets follow this structure:

```
+-----------+-----------+--------------+------------------+
| START(1B) | OPCODE(1B)| LENGTH(2B)   | PAYLOAD (0..n B) |
+-----------+-----------+--------------+------------------+
```

| Field  | Size | Description |
|---|---|---|
| **START** | 1 byte | Always `0xAA` (frame sync marker) |
| **OPCODE** | 1 byte | Operation identifier |
| **LENGTH** | 2 bytes | Payload length in bytes, big-endian |
| **PAYLOAD** | variable | Operation-specific data |

---

# 3. Opcodes

## 3.1 Python → Arduino (Commands)
| Opcode | Name | Description |
|---|---|---|
| `0x01` | Keep Alive | Ping packet used to keep BLE connection active |
| `0x02` | Change Profile | Notifies device of active profile (index + name) |
| `0x03` | Sync Profiles | Sends a dictionary of available profiles |
| `0x04` | Set RGB Key | Sets RGBW value for a single key |
| `0x05` | Set All RGB Keys | Sets RGBW values for all 16 keys at once |
| `0x06` | Lock / Unlock Device | Locks or unlocks device functionality |
| `0x07` | Hello | Protocol-version handshake sent immediately after notify subscription |

## 3.2 Arduino → Python (Events)
| Opcode | Name | Description |
|---|---|---|
| `0x81` | Keep Alive Reply | Arduino's response to keep-alive ping |
| `0x82` | Profile Changed | Arduino notifies that the user switched profile |
| `0x83` | Button Pressed | Arduino notifies that a button was pressed |
| `0x84` | Key Pressed | Arduino notifies that a keypad key was pressed |
| `0x85` | Battery Status | Arduino reports current battery level (sent after each ADC reading, ~every 30 s) |
| `0x86` | Device Telemetry | Arduino replies to `HELLO` with firmware/protocol version + runtime stats |

*(No lock event exists; locking is one-way as requested.)*

---

# 4. Payload Formats
This section defines the payload layout for each opcode.

## 4.1 Keep Alive - `0x01`
**Payload:** none

Packet:
```
AA 01 00 00
```

---

## 4.2 Change Profile - `0x02`
Notifies the device that the active profile has changed and provides its display name.

### Payload Structure
```
+------------------+
| profile_index 1B |
| name_length   1B |
| name       ...   |
+------------------+
```

- `profile_index` - integer 1..255
- `name_length` - length of profile name in bytes
- `name` - UTF-8 encoded string

> RGB colors are pushed separately via `SET_ALL_RGB_KEYS` (0x05) following the
> profile switch — that is the actual connection bootstrap sequence.

---

## 4.3 Sync Profiles - `0x03`
Sends a dictionary of `index → name` entries.

### Payload Structure
```
+------------------+
| count        1B  |
| index0       1B  |
| name0_len    1B  |
| name0        ... |
| index1       1B  |
| name1_len    1B  |
| name1        ... |
| ...              |
+------------------+
```

- `count` - number of profile entries
- For each entry:
  - `index` - profile index
  - `name_len` - name length
  - `name` - profile name (UTF-8)

---

## 4.4 Set RGB Key - `0x04`
Sets the RGBW value for a single key.

### Payload Structure
```
+--------------------+
| key_index     1B   |
| R 1B | G 1B | B 1B |
| W 1B                |
+--------------------+
```

- `key_index` - which key (0–15)
- `R,G,B,W` - color values (0–255)

---

## 4.5 Set All RGB Keys - `0x05`
Sets RGBW values for all 16 keys at once. This is typically sent when switching profiles to update all LEDs simultaneously.

### Payload Structure
```
+--------------------+
| key0  R G B W      |
| key1  R G B W      |
| key2  R G B W      |
| ...                |
| key15 R G B W      |
+--------------------+
```

- 16 × RGBW values (64 bytes total)
- Each RGBW: R(1B), G(1B), B(1B), W(1B)
- Keys are in order from 0 to 15

---

## 4.6 Lock Device - `0x06`
Locks or unlocks device functionality.

### Payload Structure
```
+----------------+
| lock_flag  1B  |
+----------------+
```

- `0x01` = lock
- `0x00` = unlock

No event/acknowledgment is generated.

Example (lock):
```
AA 06 00 01  01
```

---

## 4.7 Hello - `0x07`
Protocol-version handshake. Sent by the host immediately after it finishes subscribing to the TX notify characteristic, **before** any other command is issued.

### Payload Structure
```
+----------------------+
| protocol_version 1B  |
| app_version_len  1B  |
| app_version      ... |
+----------------------+
```

- `protocol_version` - currently `0x01` (see `PROTOCOL_VERSION` constant in `windows_app/ble_protocol.py` and `firmware/src/protocolparser.h`)
- `app_version_len` - length of the host application version string (bytes)
- `app_version` - UTF-8 encoded semver string, e.g. `"0.2.3"`

### Behaviour
Upon receipt the firmware replies with `OP_DEVICE_TELEMETRY` (`0x86`) carrying its own protocol version, firmware version, and runtime stats. The host compares `protocol_version` values: a mismatch surfaces a **CRITICAL** entry in the debug log and a warning in the status bar, then continues at the host's risk.

### Mismatch handling
`PROTOCOL_VERSION` is bumped on **any breaking change** to packet framing or payload layout. Additive changes (new opcode, additional trailing field) do **not** bump the version. Both sides must stay in lockstep — if you change one, change the other.

Example (host v0.2.3, protocol_version=1):
```
AA 07 00 07  01 05 30 2E 32 2E 33
```

---

# 5. Device → Python Events

## 5.1 Keep Alive Reply - `0x81`
**Payload:** none

Packet:
```
AA 81 00 00
```

---

## 5.2 Profile Changed - `0x82`
Sent when the user switches profile on the device.

### Payload Structure
```
+------------------+
| new_profile  1B  |
+------------------+
```

---

## 5.3 Button Pressed - `0x83`
Sent when a button (CON, BACK, PUSH) is pressed on the device.

### Payload Structure
```
+------------------+
| profile_index 1B |
| name_length   1B |
| button_name  ... |
+------------------+
```

- `profile_index` - current active profile index
- `name_length` - length of button name
- `button_name` - button identifier string (e.g., "CON", "BACK", "PUSH")

---

## 5.4 Key Pressed - `0x84`
Sent when a keypad key (0-9, A-F) is pressed on the device.

### Payload Structure
```
+------------------+
| profile_index 1B |
| key           1B |
+------------------+
```

- `profile_index` - current active profile index
- `key` - ASCII value of the key pressed (0-9, A-F)

---

## 5.5 Battery Status - `0x85`
Sent automatically after each ADC battery reading (~every 30 s) while a host is connected.

### Payload Structure
```
+-----------+
| percent 1B|
+-----------+
```

- `percent` - battery level `0–100` (integer percentage), or `0xFF` (255) when no battery is detected (e.g. device running on USB without a LiPo cell)

Example (72 % battery):
```
AA 85 00 01  48
```

Example (USB / no battery):
```
AA 85 00 01  FF
```

---

## 5.6 Device Telemetry - `0x86`
Reply to `OP_HELLO` (`0x07`). Carries the firmware's protocol version, firmware version string, and runtime statistics. Sent once per handshake; not periodic.

### Payload Structure
```
+------------------------+
| protocol_version    1B |
| fw_version_len      1B |
| firmware_version   ... |
| uptime_ms           4B |   (big-endian uint32)
| reset_reason        1B |
| free_heap           4B |   (big-endian uint32)
| ble_error_count     2B |   (big-endian uint16)
+------------------------+
```

### Fields

- `protocol_version` - device-side `PROTOCOL_VERSION` constant; compared against the host's value from `OP_HELLO`. Mismatch ⇒ host logs a CRITICAL warning.
- `fw_version_len` - length of `firmware_version` in bytes.
- `firmware_version` - UTF-8 semver string (e.g. `"1.2.3"`), from `firmware/src/version.h`.
- `uptime_ms` - milliseconds since boot, big-endian uint32. Wraps at ~49.7 days.
- `reset_reason` - byte mirroring `esp_reset_reason()`:
  - `0` = unknown
  - `1` = power-on
  - `3` = software reset
  - `5` = deep-sleep wake
  - `6` = brownout
  - `8` = task watchdog
  - `9` = interrupt watchdog
  - (full set: ESP-IDF `esp_reset_reason_t` docs)
- `free_heap` - free heap in bytes at the moment of telemetry, big-endian uint32.
- `ble_error_count` - count of malformed packets, send failures, and oversize-payload rejections since boot, big-endian uint16. A sudden spike points to radio interference or app/firmware-version drift — investigate before suspecting other layers.

Example (fw `1.2.3`, uptime 5000 ms, reset_reason=1 power-on, free_heap=200000, ble_error_count=0):
```
AA 86 00 12  01 05 31 2E 32 2E 33  00 00 13 88  01  00 03 0D 40  00 00
```

---

# 6. Encoding Notes
- All numbers are unsigned.
- All multi-byte values are big-endian.
- Strings use UTF-8 encoding.
- BLE characteristics should be configured for **binary** (not hex or text) transfer.
- No checksums are required since BLE guarantees delivery and integrity. Application-layer recovery relies on the `0xAA` start byte; the parser silently discards any bytes received outside a valid frame.
- `PROTOCOL_VERSION` (currently `1`) is the single-byte version constant exchanged in `OP_HELLO` / `OP_DEVICE_TELEMETRY`. **Bump policy:** increment on any breaking change to packet framing or payload layout. Additive changes (new opcode, new trailing field on an existing opcode) do **not** bump the version. The constant is defined in both `windows_app/ble_protocol.py` and `firmware/src/protocolparser.h` — keep them in lockstep.

---

# 7. Design Conventions
- Opcodes below `0x80` are **commands**.
- Opcodes above `0x80` are **events**.
- `0xAA` is used as a constant start byte for easy packet framing.
- Variable-length strings always use `[length][data...]` format.
- The protocol is designed to be extensible for new features.

---

# 8. Versioning
This document describes **Protocol Version 1** (`PROTOCOL_VERSION = 1`). Version negotiation is implemented via `OP_HELLO` (`0x07`) → `OP_DEVICE_TELEMETRY` (`0x86`); see §4.7 and §5.6. See §6 for bump policy.

---

# 9. License
This specification may be shared and published publicly.

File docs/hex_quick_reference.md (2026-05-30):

# BLE Protocol Hex Quick Reference

This guide helps you decode hex packets directly from the logs without needing external tools.

## Packet Structure

```
AA | OP | LL LL | [PAYLOAD...]
│    │    │        └─ Variable data (0-n bytes)
│    │    └─ Length in bytes (big-endian, 2 bytes)
│    └─ Opcode (1 byte)
└─ Start byte (always 0xAA)
```

## Quick Opcode Reference

### Commands (App → Device)
- `01` - Keep Alive (PING)
- `02` - Change Profile
- `03` - Sync Profiles
- `04` - Set RGB Key (single)
- `05` - Set All RGB Keys
- `06` - Lock/Unlock Device
- `07` - Hello (protocol-version handshake)

### Events (Device → App)
- `81` - Keep Alive Reply (PONG)
- `82` - Profile Changed
- `83` - Button Pressed
- `84` - Key Pressed
- `85` - Battery Status
- `86` - Device Telemetry (reply to Hello)

## Reading Packets

### Example 1: Keep Alive
```
aa 01 00 00
│  │  │  └─ Length low byte: 0
│  │  └─ Length high byte: 0 (payload = 0 bytes)
│  └─ Opcode: 01 (Keep Alive)
└─ Start: AA ✓
```
**Meaning**: Ping to keep connection alive, no data.

### Example 2: Profile Changed
```
aa 82 00 01 02
│  │  │  │  └─ Payload: 02 = Profile index 2 (0-based)
│  │  │  └─ Length low: 01 (1 byte payload)
│  │  └─ Length high: 00
│  └─ Opcode: 82 (Profile Changed)
└─ Start: AA ✓
```
**Meaning**: Device switched to profile 2 (3rd profile, since 0-based).

### Example 3: Set RGB Key
```
aa 04 00 05 05 ff 00 00 32
│  │  │  │  │  │  │  │  └─ W: 50 (0x32 = 50 brightness)
│  │  │  │  │  │  │  └─ B: 0
│  │  │  │  │  │  └─ G: 0
│  │  │  │  │  └─ R: 255 (0xFF = 255)
│  │  │  │  └─ Key index: 5
│  │  │  └─ Length low: 05 (5 bytes)
│  │  └─ Length high: 00
│  └─ Opcode: 04 (Set RGB Key)
└─ Start: AA ✓
```
**Meaning**: Set key 5 to red (255,0,0) at 50% brightness.

### Example 4: Sync Profiles
```
aa 03 00 10 02 01 04 54 65 73 74 02 07 44 65 66 61 75 6c 74
│  │  │  │  │  │  │  └──┴──┴──┴──┘  │  └──┴──┴──┴──┴──┴──┴──┘
│  │  │  │  │  │  │  "Test" (UTF-8) │  "Default" (UTF-8)
│  │  │  │  │  │  └─ Name length: 4 └─ Name length: 7
│  │  │  │  │  └─ Profile 1 index: 1 (1-based)
│  │  │  │  │
│  │  │  │  │  (Profile 2 block starts at the second `02`: index=2, name_len=7)
│  │  │  │  └─ Count: 2 profiles
│  │  │  └─ Length: 16 bytes (0x0010)
│  └─ Opcode: 03 (Sync Profiles)
└─ Start: AA ✓
```
**Meaning**: Sync 2 profiles:
- Profile at index 1: "Test"
- Profile at index 2: "Default"

**Length math**: count(1) + idx(1)+nlen(1)+"Test"(4) + idx(1)+nlen(1)+"Default"(7) = 16 bytes → `0x0010`.

### Example 5: Key Pressed
```
aa 84 00 02 00 41
│  │  │  │  │  └─ Key: 0x41 = 'A' (ASCII)
│  │  │  │  └─ Profile: 0
│  │  │  └─ Length: 2 bytes
│  │  └─ Length high: 00
│  └─ Opcode: 84 (Key Pressed)
└─ Start: AA ✓
```
**Meaning**: Key 'A' was pressed while on profile 0.

### Example 6: Lock Device
```
aa 06 00 01 01
│  │  │  │  └─ Lock flag: 01 = LOCKED (00 = unlocked)
│  │  │  └─ Length: 1 byte
│  │  └─ Length high: 00
│  └─ Opcode: 06 (Lock Device)
└─ Start: AA ✓
```
**Meaning**: Lock the device (workstation locked).

### Example 7: Battery Status
```
aa 85 00 01 48
│  │  │  │  └─ Payload: 0x48 = 72 (72% battery)
│  │  │  └─ Length low: 01 (1 byte payload)
│  │  └─ Length high: 00
│  └─ Opcode: 85 (Battery Status)
└─ Start: AA ✓
```
**Meaning**: Device is at 72% battery.

```
aa 85 00 01 ff
```
**Meaning**: No battery detected - device is running on USB only (`0xFF` sentinel).

### Example 8: Set All RGB Keys
```
aa 05 00 40 ff 00 00 32 ff 00 00 32 ... (64 bytes total)
│  │  │  │  └──┴──┴──┴──┘ └──┴──┴──┴──┘
│  │  │  │  Key 0: R=255    Key 1: R=255
│  │  │  │         G=0             G=0
│  │  │  │         B=0             B=0
│  │  │  │         W=50            W=50
│  │  │  └─ Length: 64 bytes (0x0040) = 16 keys × 4 bytes
│  │  └─ Length high: 00
│  └─ Opcode: 05 (Set All RGB Keys)
└─ Start: AA ✓
```
**Meaning**: Set all 16 keys to red at 50% brightness.

### Example 9: Hello (Protocol Handshake)
```
aa 07 00 07 01 05 30 2e 32 2e 33
│  │  │  │  │  │  └──┴──┴──┴──┘
│  │  │  │  │  │  ASCII "0.2.3" (app version)
│  │  │  │  │  └─ App version length: 5
│  │  │  │  └─ Protocol version: 0x01 = 1 (PROTOCOL_VERSION constant)
│  │  │  └─ Length low: 07 (7 bytes)
│  │  └─ Length high: 00
│  └─ Opcode: 07 (Hello)
└─ Start: AA ✓
```
**Meaning**: Host (app v0.2.3) announces protocol version 1; firmware should reply with `0x86 DEVICE_TELEMETRY`.

**Length math**: protocol_version(1) + name_len(1) + "0.2.3"(5) = 7 → `0x0007`.

### Example 10: Device Telemetry
```
aa 86 00 12 01 05 31 2e 32 2e 33 00 00 13 88 01 00 03 0d 40 00 00
│  │  │  │  │  │  └──┴──┴──┴──┘  └──┴──┴──┴──┘ │  └──┴──┴──┴──┘ └──┴──┘
│  │  │  │  │  │  fw "1.2.3"     uptime BE u32 │  free_heap BE  ble_err
│  │  │  │  │  │                 = 0x00001388  │  = 0x00030D40  BE u16=0
│  │  │  │  │  │                 = 5000 ms     │  = 200000 B
│  │  │  │  │  │                               └─ reset_reason: 01 = POWERON
│  │  │  │  │  └─ Firmware version length: 5
│  │  │  │  └─ Protocol version: 1
│  │  │  └─ Length low: 12 (18 bytes)
│  │  └─ Length high: 00
│  └─ Opcode: 86 (Device Telemetry)
└─ Start: AA ✓
```
**Meaning**: Firmware v1.2.3 has been up 5 s since a power-on reset, has ~200 KB free heap, and has logged zero BLE errors.

**Big-endian breakdown**:
- `uptime_ms` = `00 00 13 88` = (0×2²⁴) + (0×2¹⁶) + (0x13×2⁸) + 0x88 = 4864 + 136 = **5000 ms**
- `free_heap` = `00 03 0d 40` = (0x03×2¹⁶) + (0x0D×2⁸) + 0x40 = 196608 + 3328 + 64 = **200000 bytes**
- `ble_error_count` = `00 00` = **0**

**Length math**: pv(1) + fvlen(1) + "1.2.3"(5) + uptime(4) + reset(1) + heap(4) + ble_err(2) = 18 → `0x0012`.

**Reset reason byte** (subset of `esp_reset_reason()`):
| Value | Meaning |
|---|---|
| `00` | Unknown |
| `01` | Power-on |
| `03` | Software reset |
| `05` | Deep-sleep wake |
| `06` | Brownout |
| `08` | Task watchdog |
| `09` | Interrupt watchdog |

## Decoding Tips

### Length Field
The length is 2 bytes, big-endian:
```
00 0e → 0x000E = 14 bytes
00 40 → 0x0040 = 64 bytes
01 00 → 0x0100 = 256 bytes
```

### ASCII to Character
Common key codes:
```
30-39 → '0'-'9'
41-46 → 'A'-'F'
```

### RGB Values
```
00 → 0 (off)
80 → 128 (half)
FF → 255 (full)
```

### Profile Indices
- **In commands**: 1-based (1, 2, 3, ...)
- **In events**: 0-based (0, 1, 2, ...)

## Common Patterns

### Connection Sequence
```
1. App → Device:  aa 01 00 00              [PING]
2. Device → App:  aa 81 00 00              [PONG]
3. App → Device:  aa 03 00 0e 02...        [SYNC profiles]
4. App → Device:  aa 05 00 40 ff...        [SET all RGB keys]
```

### Profile Switch (by device)
```
1. Device → App:  aa 82 00 01 02           [Profile changed to 2]
2. App → Device:  aa 05 00 40 ff...        [Send new RGB colors]
```

### Key Press
```
1. Device → App:  aa 84 00 02 00 41        [Key 'A' pressed]
2. App executes the command for key 'A'
```

## Debugging Checklist

When reading logs:

1. **First byte = AA?** ✓ Valid packet start
2. **Second byte** → Look up opcode above
3. **Bytes 3-4** → Calculate length (big-endian)
4. **Remaining bytes** → Should match length
5. **Profile indices**:
   - Commands use 1-based
   - Events use 0-based

## Example Log Analysis

**Log entry:**
```
📁 Synchronizing 2 profiles to device...
  Profile 1: 'Main'
  Profile 2: 'Gaming'
  Packet size: 19 bytes
→ aa03000f0201044d61696e0206 47616d696e67 [SYNC]
```

**Manual decode:**
```
aa            Start ✓
03            Sync Profiles
00 0f         Length = 15 bytes
02            Count = 2 profiles
  01          Profile index 1
  04          Name length 4
  4d 61 69 6e "Main" (hex to ASCII)
  02          Profile index 2
  06          Name length 6
  47 61 6d 69 6e 67  "Gaming"
```

**Verification:** body = count(1) + 1+1+4 + 1+1+6 = 15 bytes → `0x000F`. Full packet = 4-byte header + 15 = 19 bytes. ✓

---

**Pro Tip**: Use an online hex-to-ASCII converter for quick string decoding:
- `54657374` → "Test"
- `44656661756c74` → "Default"

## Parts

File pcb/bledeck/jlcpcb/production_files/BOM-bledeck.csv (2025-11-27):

Comment | Designator | Footprint | LCSC | Quantity
PG151101S11 | S16 | Kailh_socket_MX |  | 1
PG151101S11 | S14 | Kailh_socket_MX |  | 1
PG151101S11 | S10 | Kailh_socket_MX |  | 1
PG151101S11 | S4 | Kailh_socket_MX |  | 1
Conn_01x09_Socket | J1 | oled_rotary |  | 1
WS2812B-4020 | D13 | WS2812B-4020 |  | 1
PG151101S11 | S15 | Kailh_socket_MX |  | 1
PG151101S11 | S12 | Kailh_socket_MX |  | 1
WS2812B-4020 | D7 | WS2812B-4020 |  | 1
PG151101S11 | S7 | Kailh_socket_MX |  | 1
WS2812B-4020 | D10 | WS2812B-4020 |  | 1
PG151101S11 | S11 | Kailh_socket_MX |  | 1
WS2812B-4020 | D15 | WS2812B-4020 |  | 1
PG151101S11 | S8 | Kailh_socket_MX |  | 1
Conn_01x02_Socket | J2 | PinHeader_1x02_P2.54mm_Vertical |  | 1
PG151101S11 | S6 | Kailh_socket_MX |  | 1
PG151101S11 | S9 | Kailh_socket_MX |  | 1
WS2812B-4020 | D11 | WS2812B-4020 |  | 1
WS2812B-4020 | D2 | WS2812B-4020 |  | 1
PG151101S11 | S2 | Kailh_socket_MX |  | 1
ESP32-DEVKIT-V1 | U1 | MODULE_ESP32_DEVKIT_V1 |  | 1
WS2812B-4020 | D14 | WS2812B-4020 |  | 1
WS2812B-4020 | D3 | WS2812B-4020 |  | 1
PG151101S11 | S13 | Kailh_socket_MX |  | 1
PG151101S11 | S5 | Kailh_socket_MX |  | 1
WS2812B-4020 | D6 | WS2812B-4020 |  | 1
WS2812B-4020 | D5 | WS2812B-4020 |  | 1
PG151101S11 | S1 | Kailh_socket_MX |  | 1
WS2812B-4020 | D4 | WS2812B-4020 |  | 1
WS2812B-4020 | D1 | WS2812B-4020 |  | 1
WS2812B-4020 | D16 | WS2812B-4020 |  | 1
WS2812B-4020 | D12 | WS2812B-4020 |  | 1
WS2812B-4020 | D9 | WS2812B-4020 |  | 1
PG151101S11 | S3 | Kailh_socket_MX |  | 1
WS2812B-4020 | D8 | WS2812B-4020 |  | 1
15k | R1 | R_Axial_DIN0207_L6.3mm_D2.5mm_P7.62mm_Horizontal |  | 1
4.3k | R2 | R_Axial_DIN0207_L6.3mm_D2.5mm_P7.62mm_Horizontal |  | 1

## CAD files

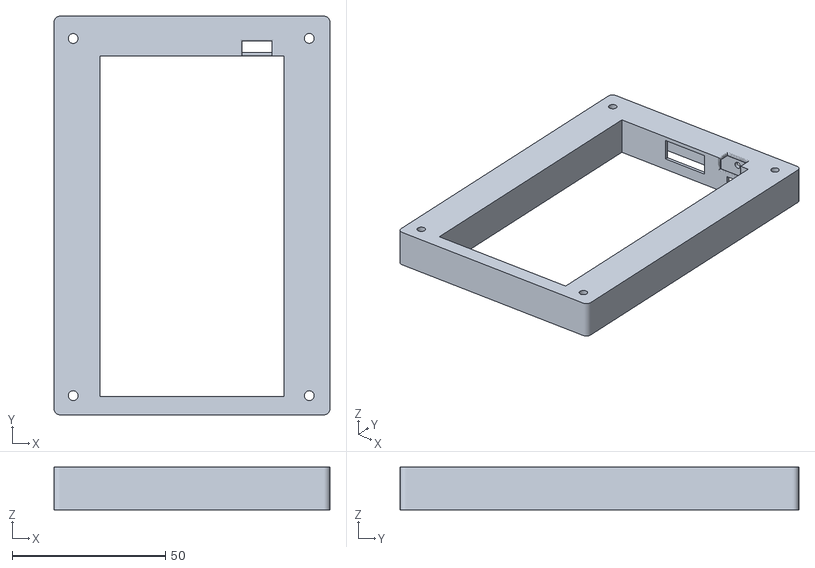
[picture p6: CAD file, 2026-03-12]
enclosure/stls/BatteryLayer.stl
90.0 x 130.0 x 14.0

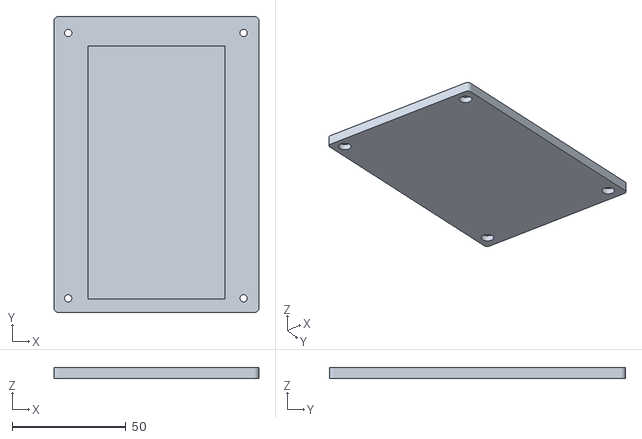
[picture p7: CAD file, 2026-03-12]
enclosure/stls/Bottom.stl
90.0 x 130.0 x 5.00

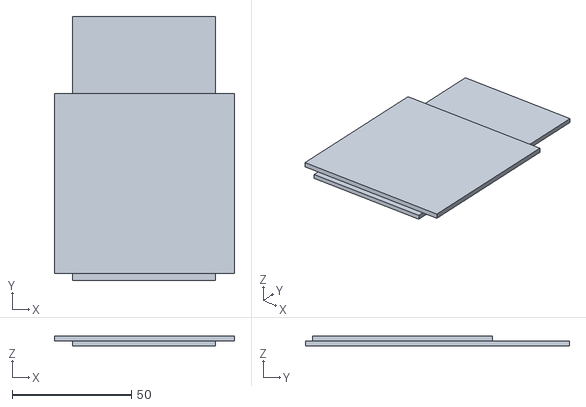
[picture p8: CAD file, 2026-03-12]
enclosure/stls/BatteryTop.stl
75.6 x 111.0 x 4.20

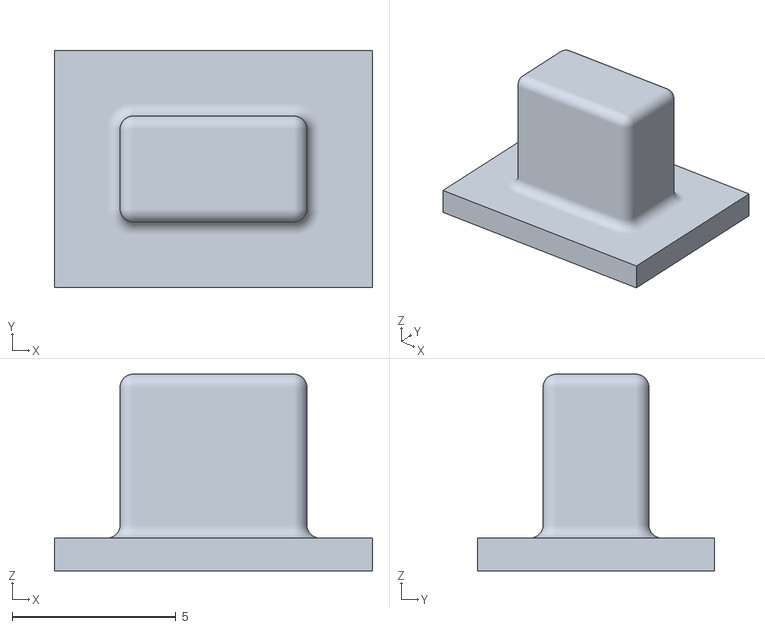
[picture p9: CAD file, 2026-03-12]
enclosure/stls/PushButton.stl
9.70 x 7.23 x 6.00

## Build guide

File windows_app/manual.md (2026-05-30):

# BLEDeck — User Manual

BLEDeck is a 16-key Bluetooth Low Energy macro pad. This Windows app is the
control panel: it pushes profiles, RGB colors, and key actions to the device,
and reacts to physical key presses by running shell commands or recorded
macros on your PC.

The device itself stores nothing permanently — every time you connect, the app
re-sends the active profile.

---

## 1. Getting started

1. Power on the BLEDeck device.
2. Launch the app. It opens in **Pad** mode with the default profile loaded
   from `%APPDATA%\BLEDeck\profiles.json`.
3. Click **Connect**. The status bar shows *Connecting...* while the app scans
   for a device advertising as `BLEDeck`. Once paired, it shows
   *Connected to <address>*.
4. Tick **Auto-reconnect** to have the app automatically re-establish the
   connection if the link drops.

The battery indicator next to the status appears once connected:
`Bat: 42%` for a battery-powered device, `USB` when it is on cable power.

---

## 2. Modes

Switch via the **Mode** menu.

### Pad mode (default)

Clean, compact interface for daily use. The 4×4 key grid fills the window;
the profile dropdown lets you switch profiles; nothing else is editable.
This is the mode to leave the app in once you have configured it.

### Edit mode

Full editing surface. On top of the Pad widgets, you also get:

- Profile name field and **New Profile / Save Profile / Delete Profile**
  buttons.
- Key configuration panel: label, color picker, brightness slider, action
  type (Command or Macro), command field with file browser, macro editor
  launcher.

The window grows to ~900×700 to fit the extra controls. Switch back to Pad
when you're done editing.

---

## 3. The File menu

Profiles live in JSON files. The default file is at
`%APPDATA%\BLEDeck\profiles.json` and loads automatically each launch. You
can open a different file for the current session — useful for testing setups
or sharing configurations.

| Action | Shortcut | Behavior |
|---|---|---|
| **New** | `Ctrl+N` | Discards the current file (after a save prompt if dirty) and starts a blank profile. The window title shows `[Unsaved]` until saved. |
| **Open...** | `Ctrl+O` | Opens any `*.json` profile file. The path is shown in the window title for the rest of the session. |
| **Save** | `Ctrl+S` | Writes back to the current file. If the current file is new (never saved), you are prompted: *Save as Default* (overwrites the APPDATA file) or *Save As...* (pick a custom location). When saving as Default with an existing file, a confirmation warns about the overwrite. |
| **Exit** | `Ctrl+Q` | Closes the app. Same dirty-changes prompt as the title bar X. |

An asterisk (`*`) in the title means there are unsaved changes.

> The **Save Profile** button in Edit mode runs the exact same logic as
> File → Save.

---

## 4. Profiles

A profile file holds an ordered list of profiles. Each profile has a name and
up to 16 keys. The device supports up to **10 profiles** (protocol limit).

- The **Profile** dropdown switches the active profile. The device follows.
- The device's rotary encoder also switches profiles; the app follows.
- **New Profile** appends an empty profile to the current file.
- Edit the name in the text field; the change is saved with the file.
- **Delete Profile** removes the current profile (at least one must remain).

---

## 5. Configuring a key (Edit mode)

1. Click any key in the 4×4 grid. The label `Selected Key: <name> (ID: <n>)`
   updates.
2. **Label** — short text shown on the key in the app. The device itself
   doesn't show labels — only the RGB color.
3. **Color** — enter `R,G,B,Brightness%` directly (e.g. `255,0,0,70`) or click
   **Pick Color** for a color dialog. The brightness slider rescales the
   brightness component (0–100%). The LED on the device updates instantly.
4. **Action** — choose **Command** or **Macro**.

### Command action

A shell command or executable path. Examples:

- `notepad.exe`
- `calc.exe`
- `"C:\Program Files\My App\tool.exe"`
- `cmd /c echo Hello`

Use **Browse...** to pick an `.exe`. Quote any path containing spaces.

When the device sends `KEY_PRESSED` for this key, the app launches the
command (non-blocking; the app does not wait for it to exit).

### Macro action

Records a sequence of mouse clicks, key presses, and pauses to replay on
demand. Click **Edit Macro...** to open the macro editor.

A re-entrancy guard prevents the same key from launching two parallel macros:
if you press the device key while a previous run is still in progress, the
new press is skipped (visible as `⚠️ Key X still running, skipping` in the
debug log).

---

## 6. The macro editor

Opened from a Macro-type key's **Edit Macro...** button.

> ⚠️ **Capture risk.** Recording uses a global keystroke / mouse listener — it
> sees **everything you type while it's running**, including passwords typed
> into other windows. Two safeguards are built in:
>
> - The recorder **auto-stops after 60 seconds of idle time** so a forgotten
>   session cannot silently capture later activity.
> - The captured macro is stored in `profiles.json` in plain text. Keep that
>   file out of public sync folders or Git repositories.
>
> Treat the editor like a temporary screen recorder, not a keylogger you walk
> away from. Hit **Stop** (or press `Esc`) the moment you've captured the
> sequence you wanted.

| Button | What it does |
|---|---|
| **Record** | Captures every mouse click and key press as a step. Press `Esc` to stop. |
| **Stop** | Stops an in-progress recording. |
| **Test Run** | Plays the current macro back immediately. |
| **Edit Step** | Modify the selected step (double-click works too). |
| **Delete Step** | Remove the selected step. |
| **Clear** | Remove all steps. |

Steps can be drag-reordered in the list.

### Step types

- **Click** — `x, y, button, anchor`
- **Key** — single key plus optional modifiers (`ctrl`, `shift`, `alt`, `win`)
- **Sleep** — pause for *N* milliseconds

### Click anchors

Mouse clicks are recorded relative to a reference, so playback still works
when windows have moved. Three anchor kinds:

| Anchor | Meaning |
|---|---|
| `window:<title>` | Coordinates relative to the top-left of the named window. The window is found again at playback time. Use `window:` (empty title) to mean *the current foreground window*. |
| `monitor:<N>` | Relative to the top-left of monitor *N* (0 = leftmost). Use this for clicks on the taskbar or empty desktop. |
| `abs` | Absolute screen coordinates. |

The recorder picks an anchor automatically based on where you click:
foreground app windows produce `window:` anchors; taskbar/desktop clicks
produce `monitor:` anchors.

---

## 7. Device-side feedback

Some things happen at the device that the app reacts to:

- **Profile change via the encoder** — the app switches profiles to match and
  re-sends RGB colors.
- **Button press** (encoder push / back / con) — logged in the debug panel.
- **Key press** — the configured Command or Macro for that key runs.
- **Battery status** — sent ~every 30 seconds; updates the battery readout.

---

## 8. Screen lock awareness

When Windows is locked (Win+L, or your screensaver triggers the lock), the
app notifies the device. The device shows a lock icon on the OLED and ignores
key presses until unlocked. This avoids macros firing while you are away.

---

## 9. Tray and minimize

Closing or minimizing the window hides it to the system tray instead of
quitting.

- Double-click (or single-click on most Windows setups) the tray icon to
  restore.
- Right-click the tray icon for **Open** / **Quit**.

Profile changes triggered from the device (via the rotary encoder) are
recorded in the debug log; the app updates state silently while hidden.

---

## 10. Help menu

| Item | What it does |
|---|---|
| **Manual** | Opens this document. |
| **Enable Debug** | Shows the *Debug Log* panel for the current session. It logs every BLE packet sent and received, plus high-level state changes. Turned off by default; not persisted across launches. |
| **Info** | Shows the app version, authors, and a link to the project on GitHub. |

---

## 11. Where things live

| Item | Location |
|---|---|
| Default profile file | `%APPDATA%\BLEDeck\profiles.json` |
| Custom profile files | Anywhere you save them; tracked per session via File → Open |
| App icon | `icon.ico` in the install directory |
| This manual | `manual.md` in the install directory |

The `%APPDATA%\BLEDeck` folder is created automatically on first run. If it
cannot be created (locked-down profile, missing `%APPDATA%`, etc.), the app
falls back to `~/.bledeck` and then to the system temp directory so the app
always starts.

---

## 12. Connection health

- The app pings the device every 10 seconds.
- If the device misses pings for 30 seconds (e.g. the app crashes), it drops
  the connection on its own.
- If the device drops, **Auto-reconnect** retries every 10 seconds.

These intervals are tuned to detect a dead app in under a minute while
tolerating brief radio glitches.

---

## 13. Limitations

- **Windows only.** PyQt5 + bleak + Win32 helpers; no macOS or Linux support.
- **10 profiles max, 16 keys per profile** — protocol limit.
- **Single device.** The app pairs with the first device advertising as
  `BLEDeck`.
- **Macro recorder captures press events only.** Mouse movement paths and
  release timings are not recorded; sleeps between actions are inferred from
  natural pauses.

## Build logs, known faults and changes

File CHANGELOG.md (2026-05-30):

# Changelog

Covers: `enclosure`, `firmware`, `pcb`, `simulator`, `windows_app`.

## Latest releases (2026-05-30)

| Component | Version | Headline |
|---|---|---|
| `firmware` | **v1.2.5** | `loop()` yield when connected; WS2812B refresh coalesced at 60 Hz |
| `windows_app` | **v0.2.6** | `pyproject.toml` packaging; unified `run-tests` scripts; Help → Forget paired device + view-source buttons; truthful pytest pin |
| `simulator` | **v0.1.2** | `OP_HELLO` handler replies with `OP_DEVICE_TELEMETRY` |
| `pcb` | v1.1 | (last release — no changes this cycle) |
| `enclosure` | v1.0.0 | (last release — no changes this cycle) |

Update this table on every release. Detailed bullets per version live in the
per-component sections below.

---

## windows_app

### v0.2.6 — 2026-05-30
- Security: bumped `markdown` `3.7` → `3.10.2` (PYSEC-2026-89 — unhandled `AssertionError` DoS on malformed Markdown) and `pytest` `<9` → `>=9.0.3` (CVE-2025-71176 — predictable `/tmp/pytest-of-*` dir on UNIX); lifted the stale `pytest-asyncio<1` cap to `>=1.4` and `pytest-benchmark` to `>=5`. Clears all three Dependabot alerts; 258 tests still green under pytest 9
- DX: `pyproject.toml` at repo root — single `pip install -e .[dev]` (or `.[dev,build]`) replaces the three `requirements*.txt` install dance; declares `windows_app`/`simulator`/`debug` packages and registers `bledeck-decode` as a console script
- DX: cross-platform `setup-dev.sh` mirrors `setup-dev.bat`; both now install runtime + dev + build deps and verify with `pytest` in one shot
- DX: `run-tests.bat` / `run-tests.sh` at repo root — unified runner for Python suites + firmware native Unity tests; clean SKIP when `pio` is absent
- DX: Help menu now has **Forget paired device** — clears `preferred_device_mac` in `app_settings.json` with a confirmation dialog (no more hand-editing JSON)
- DX: Help → Manual dialog gets two new ActionRole buttons — **View source on GitHub** and **Open in browser** — so users can share / print a section
- DX: `Connect → Device not found` now prints 3 actionable hints (BT enabled? device on? troubleshooting doc link) and status bar reads "Device not found — see logs"
- DX: `bench_protocol.py` `importorskip` carries an explicit install hint instead of a silent skip
- DX: `requirements-dev.txt` pin truthified — `pytest>=8.3,<9` matches the installed version (the prior `pytest==9.0.3` pin was a lie; pytest-asyncio caps pytest <9)
- DX: README + simulator/README ship a three-row `BLEDECK_SIM=1` syntax table (cmd / PowerShell / Git Bash) so PowerShell users no longer get bitten by the `&&` separator
- DX: `docs/troubleshooting.md` adds a callout pointing readers at `Help → Enable Debug` when triaging no-connect reports
- DX: `firmware/README.md` Native unit tests section spells out the host-gcc prerequisite (w64devkit / scoop / choco / apt / xcode-select)
- DX: `CHANGELOG.md` gets a "Latest releases" table at the top — one-glance view of the current HEAD across every component
- Legal: added repo-root `LICENSE` (MIT) and reconciled the README License section + `pyproject.toml` (`0.2.6`, was a stale `0.2.5`) to all state MIT consistently; `bledeck.spec` now bundles `LICENSE` into the packaged app
- Docs: corrected three README inaccuracies — `profiles.json` lives in `%APPDATA%\BLEDeck\` (not next to the exe), the macro recorder captures clicks + keystrokes (not mouse movement) and auto-stops after 60 s, and the simulator dedicated-venv install now points at the pinned `simulator/requirements.txt`
- Docs: `CONTRIBUTING.md` carries the full protocol-change file table inline (no longer delegating to a non-shipped file); PR template points at it
- Test: added `tests/test_macro_player.py` (14) — anchor resolution (window/monitor/abs), the `_resolve_key` multi-char safety guard, and click-offset/modifier-order playback; closes the only untested business-logic module
- Test: benchmarks are now actually deselected by default via `addopts = "-m 'not benchmark'"` (declaring the marker alone never skipped them once `pytest-benchmark` was installed)
- Refactor: hoisted the per-notification opcode-label dict to a module constant `_OP_NAMES` (no realloc per packet)
- Resilience: window-close BLE-disconnect poll now self-terminates at a ~10 s ceiling, so a wedged BLE stack can never make the window un-closable
- Cleanup: removed an unused `pathlib.Path` import in `app_settings.py`

### v0.2.5
- Perf: connection bootstrap waits on `OP_DEVICE_TELEMETRY` and `OP_KEEP_ALIVE_REPLY` instead of two hardcoded `asyncio.sleep(0.5)` calls. First-key-ready latency after Connect drops from ~1.6 s to <300 ms on a healthy link
- Perf: added `_opcode_waiters` map + `_await_opcode(opcode, timeout)` helper; `handle_notification` resolves the matching future as soon as a packet arrives (does not short-circuit dispatch)
- Perf: colour / brightness edits debounced via a 50 ms `QTimer` (`_color_send_timer` + `_pending_color_packet`); slider drag now collapses to ~20 Hz BLE writes instead of one per integer tick
- Perf: `self.log()` short-circuits ping/pong / `[PING]` / `[PONG]` lines when the Debug Log panel is hidden — saves the `data.hex()` interpolation + QTextEdit append on every keep-alive cycle
- Perf: rotating file handler wrapped with `QueueHandler` + `QueueListener` — disk I/O runs on a background thread, GUI thread never blocks on a slow `bledeck.log` write; listener stopped cleanly in `closeEvent`
- Perf: `ActionRunner` reuses a shared `ThreadPoolExecutor(max_workers=4)` instead of spawning a fresh `threading.Thread` per device keypress; `atexit` shutdown with `cancel_futures=True` so stuck shell commands no longer block interpreter exit
- Added: `tests/bench_protocol.py` (NEW) — 9 microbenchmarks under `pytest-benchmark`; skips cleanly when the package is missing. Default `pytest` runs still exclude them via the `benchmark` marker
- Added: `pytest-benchmark>=4,<6` to `requirements-dev.txt`

### v0.2.4
- Refactor: extracted `RISKY_COMMAND_TOKENS` + `collect_risky_commands()` into new `command_safety.py` module (pure function, no GUI dependency); `BLEDeckGUI._collect_risky_commands` is now a one-line shim
- Added tests: `test_app_settings.py` (7), `test_log_filter.py` (6 — pins the `[PING]`/`[PONG]` regression), `test_command_safety.py` (9), `test_macro_recorder.py` (4)
- Added contract / integration tests: `test_contract.py` (11) — app builders ↔ simulator handler byte equivalence; `test_decoder_contract.py` (10) — every builder decoded correctly by `debug/protocol_decoder.py`; `test_handshake.py` (4) — full connect sequence (HELLO → TELEMETRY → SYNC → CHANGE → SET_ALL_RGB)
- Added: `pytest-asyncio>=0.24,<1` to `requirements-dev.txt` (needed for `test_cli.py` in simulator)
- Note: pytest transitively downgraded to `8.4.2` to satisfy `pytest-asyncio` upper bound on pytest 9

### v0.2.3
- Added: rotating file log at `%APPDATA%\BLEDeck\logs\bledeck.log` (5 × 20 MB, 100 MB cap); `KEEP_ALIVE` traffic filtered out for readability
- Added: app sends `OP_HELLO` on connect; firmware replies with `OP_DEVICE_TELEMETRY`; mismatched `PROTOCOL_VERSION` surfaces a CRITICAL log line
- Added: exponential backoff on auto-reconnect — 10 s → doubles → capped at 5 min; resets after a successful connect
- Added: preferred device MAC pinned in `%APPDATA%\BLEDeck\app_settings.json` after first successful connect; multiple BLEDecks in range now favour the previously-used one
- Added: `WTS_SESSION_LOCK` subscription replaces the 2.5 s workstation-lock poll — sub-50 ms lock-detection latency
- Added: profiles.json load surfaces a `QMessageBox.warning` listing high-risk command tokens (`powershell`, `cmd /c`, `curl … | iex`, etc.) so untrusted files cannot fire silently
- Added: macro recorder auto-stops after 60 s of idle time to limit accidental capture
- Documentation: new `docs/troubleshooting.md`; macro capture risk callout added to `manual.md`

### v0.2.2
- Added: `BLEPacket.parse` enforces `MAX_PAYLOAD_LEN = 256` cap and rejects truncated frames (parity with firmware + simulator)
- Added: `tests/test_hardening.py` — 13 regression tests covering `_resource_path`, atomic save, schema v1 round-trip, and `BUTTON_PRESSED` parser contract
- Added: profiles.json schema v1 — file now wraps `{"version": 1, "profiles": [...]}`; legacy bare-list files load and migrate on next save
- Added: `requirements-dev.txt` for test-only dependencies (`pytest` moved out of runtime requirements)
- Added: `_resource_path()` resolver — icon and manual now load correctly in PyInstaller frozen builds via `_MEIPASS`
- Added: `.corrupt.json` backup on profiles.json parse failure (defaults restored, GUI keeps starting)
- Added: `%APPDATA%` mkdir failure falls back to `~/.bledeck` then `tempfile.gettempdir()/bledeck`
- Added: atomic write of profiles.json (tmp + `os.replace`) — no half-written files on crash
- Added: command actions launched in worker thread (no GUI freeze on slow paths)
- Added: `MacroDialog` Test Run button disabled while playback active; signal-driven re-enable
- Added: `_sample: True` marker on the three pre-filled default keys (Notepad/Calc/Explorer) for future first-run UX
- Fixed: truncated `APP_VERSION` string in `__version__.py` (`"0.2."` → `"0.2.1"`)
- Fixed: `parse_key_pressed` rejects non-hex bytes (firmware only emits 0-9/A-F)
- Fixed: `BUTTON_PRESSED` bounds-checks profile index (parity with KEY_PRESSED)
- Fixed: `_render_manual_html` ImportError fallback now returns escaped `<pre>` (no raw markdown)
- Changed: profile-name buffer raised to 39 B (matches firmware buffer minus NUL); warns on truncation
- Changed: narrowed bare `except Exception` in `win32_utils.py`; `asyncio.CancelledError` re-raised in notification handler

### v0.2.1
- Fixed: GUI applications (notepad, calc, etc.) launched hidden due to `STARTF_USESHOWWINDOW`; now uses `CREATE_NO_WINDOW` which suppresses console flash without hiding GUI windows
- Fixed: Pad mode key clicks ran the edit-selection handler instead of executing the assigned action; added `_on_key_click()` routing (Pad → execute action, Edit → select key for config)
- Added: installer script (`build.bat` + `bledeck.spec`) to package app as standalone Windows executable via PyInstaller
- Added: `__version__.py` as single source of truth for app name, version, and metadata

### v0.2.0
- Added: macro recorder and player — captures mouse clicks and keystrokes with window/monitor-relative coordinate anchoring
- Added: `MacroDialog` — record, edit, reorder, delete, and test-run macro steps
- Added: two action types per key: Command (shell) and Macro
- Added: multi-monitor support; monitors indexed by left edge (0 = leftmost)
- Added: macro step types: `ClickStep`, `KeyStep`, `SleepStep` with JSON serialization
- Added: `pynput`-based recorder with per-click window anchor detection
- Added: `macro_player.py` with anchor resolution at play time

### v0.1.0
- Initial release
- BLE scan, connect, auto-reconnect
- 4×4 key grid with per-key label, RGBW color, and shell command action
- Profile management: create, rename, save, delete; stored in `%APPDATA%\BLEDeck\profiles.json`
- Live RGB sync on color change
- Battery indicator
- System tray minimize
- Profile switching via encoder on device (PROFILE_CHANGED event)
- Workstation lock/unlock via LOCK_DEVICE opcode

---

## simulator

### v0.1.2 — 2026-05-30
- Added: `OP_HELLO` command handler — replies with `OP_DEVICE_TELEMETRY` using simulator-provided fields
- Added: `event_emitter.device_telemetry()` builder
- Tests: new HELLO/telemetry round-trip tests under `simulator/tests/test_command_handler.py`
- Tests (post-release): `tests/test_cli.py` (18) — REPL exit paths (`q`/`quit`/`exit`/EOF/blank), `battery` clamping, `press` validation, `profile` bounds, `help`/`state`/unknown-command paths

### v0.1.1
- Fixed: CHANGE_PROFILE handler now parses and stores the name payload (was dropped — diverged from firmware)
- Added: input validation on CLI `battery`/`press`/`profile` commands (rejects out-of-range / malformed values before emitting)
- Added: malformed and truncated packets logged at DEBUG with offending bytes
- Added: oversized payloads (>256 B) rejected to match firmware `MAX_PAYLOAD_LEN`
- Added: `_handle_write` wraps cmd dispatch in try/except with raw-byte logging (deferral always completes)
- Added: `_context.reset_state()` helper for test isolation; autouse fixture in `conftest.py`
- Changed: `FakeBleakClient` registers itself on `connect()`, not `__init__` (avoids ghost active clients across reconnects)
- Changed: user-facing fallback messages in `__main__.py` use `logger` instead of `print`
- Fixed: misleading `--loopback` help text (loopback is the default — no flag needed)
- Pinned: `bleak==3.0.2` with required `winrt-*` sub-packages
- Removed: dead `_BLESS_AVAILABLE` flag and `bless` compatibility comments

### v0.1.0
- Initial release
- Mode A (loopback): `FakeBleakClient` / `FakeBleakScanner` in-process fake — no Bluetooth needed; activated by `BLEDECK_SIM=1`
- Mode B (real BLE): WinRT `GattServiceProvider` GATT server via `--ble` flag; requires two machines
- CLI REPL: `battery`, `press`, `button`, `profile`, `state`, `help`, `quit` commands
- `DeviceState` dataclass for profiles, RGB matrix, lock, battery
- `command_handler.py` handles all PC→Device opcodes (KEEP_ALIVE, CHANGE_PROFILE, SYNC_PROFILES, SET_RGB_KEY, SET_ALL_RGB_KEYS, LOCK_DEVICE)
- `event_emitter.py` builds Device→PC events (BATTERY_STATUS, KEY_PRESSED, BUTTON_PRESSED, PROFILE_CHANGED)

#### Known limitations
- Mode B (real BLE GATT server) is Windows-only (WinRT-backed)
- Same-machine BLE self-connection is not supported by Windows; Mode B requires two machines

---

## firmware

### v1.2.5 — 2026-05-30
- Perf: `loop()` now yields with `vTaskDelay(1)` when a BLE session is active, keeping the existing 10 ms `delay()` only on the disconnected idle path. Keypress→dispatch latency drops from ~10 ms worst case to ~1 ms while connected; the disconnected idle animation keeps its power-save sleep
- Perf: WS2812B strip refresh coalesced at ~60 Hz via a `rgbShowPending_` flag + `rgbFlush()` pump called from `loop()`. Bursts of per-key `OP_SET_RGB_KEY` updates (e.g. brightness-slider drag) collapse into one strip write per ~16 ms instead of one per packet — saves ~7.7 ms per dropped `Show()` call
- `kRgbMinFrameIntervalMs = 16` constant exposes the limiter window in `main.cpp`

### v1.2.4
- Refactor: extracted OTA auth-failure rate-limit logic from `OtaManager` into a header-only `OtaRateLimiter` struct in `ota_manager.h` so it can be exercised by host-side Unity tests. Algorithm unchanged; `OtaManager` now delegates `isLockedOut()` / `recordFailure()` to the struct
- Added: `[env:native]` PlatformIO environment for host-side Unity tests (`pio test -e native` — no ESP32 required)
- Added tests: `test/test_protocol_parser/test_main.cpp` (6) — zero-length, single-byte, garbage resync, oversize drop, multi-byte, max-size edge case
- Added tests: `test/test_ota_rate_limit/test_main.cpp` (5) — lockout after 5 failures within 60 s, spread-failure non-lockout, lockout clears after 5 min, recordFailure safe during active lockout
- Documentation: `firmware/README.md` now documents the `native` test env

### v1.2.3
- Added: `OP_HELLO` (0x07) PC → Device opcode for protocol version handshake
- Added: `OP_DEVICE_TELEMETRY` (0x86) Device → PC opcode — sent on every `OP_HELLO`; payload includes firmware version, uptime, reset reason, free heap, BLE error count
- Added: `PROTOCOL_VERSION = 1` constant in `protocolparser.h`; bump for breaking protocol changes
- Added: OTA HTTP auth rate-limit infrastructure (`OtaRateLimiter`) — 5 failed attempts within 60 s arm a 5-minute lockout. The lockout gate is checked in `OtaManager::loop()`, but ElegantOTA 3.1.7 exposes no auth-failure callback, so failures are not yet recorded and the lockout stays dormant until the library gains an `onAuthFail` hook or the upload routes are self-hosted
- Added: BLE error counter exposed via `OP_DEVICE_TELEMETRY`
- Documentation: ESP32 task watchdog assumptions now spelled out in `main.cpp` above `setup()`

### v1.2.2
- Added: BLE MTU negotiated to 247 in `setup()` (avoids silent truncation of notifies >20 B)
- Added: `BAT_CALIBRATION` constant in `configuration.h` to absorb the ESP32 ADC2/attenuation over-read on GPIO 13. Empirically tuned to `0.3607`; tune per board against a multimeter
- Added: unconditional `[BAT] adc=… mV vbat=… mV pct=…` serial line every 30 s for calibration (no more `DEBUG_SERIAL` gate on this one line)
- Added: `MAX_PROFILES = 10` documented in `protocolparser.h` protocol comment block
- Fixed: battery divider constants `BAT_R1=15000` / `BAT_R2=4300` now match the soldered PCB (the schematic Value fields are wrong)
- Fixed: `BAT_INTERVAL_S` renamed to `BAT_INTERVAL_MS` (name matches units)
- Fixed: OLED brightness restored to 255 on unlock (was 100 — screen stayed dim after first lock)
- Fixed: ping-timeout disconnect now sets `deviceConnected` / `oldDeviceConnected` flags defensively so the loop's cleanup branch always runs
- Fixed: OTA cancel via BACK requires ≥1000 ms hold (avoids restart between user click and ElegantOTA `onStart` callback)
- Fixed: `sendBatteryStatus()` body now wrapped in `#ifdef USE_BATTERY` for symmetry
- Fixed: `rgbColors` "all-keys" sentinel changed from magic `99` to `-1` (safe against future `RGB_NUM` growth)
- Changed: `rgbColors` reworked from `std::vector<String>` to packed `RGBW[]` (4 B per key) — eliminates per-update heap fragmentation; `splitColorsString` parser removed
- Fixed: `credentials.h.example` renamed `OTA_PASSWORD` → `OTA_HTTP_PASSWORD` with explanatory comment
- Changed: `splitColorsString` converted to `template<size_t N>` — array-size mismatch caught at compile time
- Changed: removed dead `try/catch` around `notify()` (ESP32 Arduino is built `-fno-exceptions`)
- Changed: non-error `Serial.print*` calls gated behind `#ifdef DEBUG_SERIAL` (off by default)
- Changed: OTA AP password length bumped from 8 to 12 characters (~60 bits entropy)
- Pinned: `platform = espressif32@6.9.0` and `ElegantOTA=3.1.7` for reproducible builds

### v1.2.1
- Added: OTA update support via ElegantOTA (long-press encoder PUSH → settings menu → OTA Update)
- Added: WiFi STA connect with AP fallback (`BLEDeck-OTA`) for OTA mode
- Added: custom partition table (`partitions_ota.csv`) for larger OTA partition
- Added: `version.h` — single source of truth for firmware version constants
- Fixed: workstation lock detection and display
- Fixed: connection timeout after `BLE_PING_TIMEOUT_MS` (30 s) without KEEP_ALIVE

### v1.1.0 — matches pcb v1.1
- Enabled 16 WS2812B RGB LEDs (full 4×4 matrix)
- Changed key layout to match PCB v1.1 footprint
- Added battery voltage reporting (`OP_BATTERY_STATUS 0x85`) with 5-sample rolling average
- TX power set to +9 dBm maximum

### v1.0.0
- Initial release
- BLE GATT server advertising as `BLEDeck`
- Binary framed protocol (START 0xAA | OPCODE | LENGTH(2) | PAYLOAD)
- Profile management: SYNC_PROFILES, CHANGE_PROFILE, PROFILE_CHANGED
- Per-key RGB scaffolding: SET_RGB_KEY, SET_ALL_RGB_KEYS opcodes (full 16-LED matrix lit in v1.1.0)
- Key press events: KEY_PRESSED (profile_index + key_char)
- Named button events: BUTTON_PRESSED (CON, BACK, PUSH)
- Rotary encoder cycles profiles; idle RGB animation when disconnected
- SSD1306 OLED: profile name, connection status, battery
- Workstation lock: LOCK_DEVICE suppresses key/encoder events, dims OLED

---

## pcb

### v1.1
- Fixed key switch footprint connections
- Fixed LED traces for WS2812B-4020 side-emitting layout
- Fixed OLED footprint and pin connections
- Rerouted all tracks and vias
- Evenly spaced key grid

### v1.0
- Initial two-layer KiCad design
- ESP32 DevKitC v1, 16 Gateron key switches, SSD1306 OLED, EC11 encoder
- Battery connector with 15 kΩ / 4.3 kΩ voltage divider on GPIO 13
- Gerbers for JLCPCB included

---

## enclosure

### v1.0.0
- Initial 3D printable enclosure in PLA
- Parts: `PushButton.stl` (×2), `KeyboardLayer.stl`, `BatteryTop.stl`, `BatteryLayer.stl`, `Bottom.stl`

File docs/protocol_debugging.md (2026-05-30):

# BLE Protocol Debugging Guide

This guide explains how to debug the binary protocol communication between the Windows app and the Arduino firmware.

## Overview

The protocol uses binary packets with the following structure:
```
[START_BYTE][OPCODE][LENGTH_H][LENGTH_L][PAYLOAD...]
```

- **START_BYTE**: Always `0xAA`
- **OPCODE**: Command/Event identifier (1 byte)
- **LENGTH**: Payload length in bytes, big-endian (2 bytes)
- **PAYLOAD**: Variable-length data (0–256 bytes max)

## Using the Protocol Decoder

The `protocol_decoder.py` script can decode hex strings and explain all operations.

### Command Line Usage

```bash
# Decode a single packet
python protocol_decoder.py aa010000

# Decode with spaces
python protocol_decoder.py "aa 01 00 00"

# Show test examples
python protocol_decoder.py test
```

### Interactive Mode

```bash
python protocol_decoder.py

# Then enter hex strings at the prompt
> aa010000
> aa82000102
> test
> quit
```

## Common Packets

### Commands (App → Device)

#### Keep Alive (0x01)
```
aa 01 00 00
```
- No payload
- Sent periodically to maintain connection

#### Sync Profiles (0x03)
```
aa 03 00 0e 02 01 04 54657374 03 07 44656661756c74
```
- Byte 4: Count (0x02 = 2 profiles)
- For each profile:
  - Profile index (1-based)
  - Name length
  - Name bytes (UTF-8)

Example breakdown:
- `02` - 2 profiles
- `01 04 54657374` - Profile 1: length=4, name="Test"
- `03 07 44656661756c74` - Profile 3: length=7, name="Default"

#### Set RGB Key (0x04)
```
aa 04 00 05 05 ff 00 00 32
```
- Byte 4: Key index (0-15)
- Byte 5-8: R, G, B, W values

#### Set All RGB Keys (0x05)
```
aa 05 00 40 [64 bytes of RGBW data]
```
- 16 keys × 4 bytes = 64 bytes total
- Each key: R, G, B, W (1 byte each)

#### Lock Device (0x06)
```
aa 06 00 01 01    (locked)
aa 06 00 01 00    (unlocked)
```

#### Hello (0x07)
Protocol-version handshake, sent immediately after notify subscription.
```
aa 07 00 07 01 05 30 2e 32 2e 33
│  │  │  │  │  │  └──┴──┴──┴──┘
│  │  │  │  │  │  "0.2.3" (UTF-8 app version)
│  │  │  │  │  └─ App version length: 5
│  │  │  │  └─ Protocol version: 1
│  │  │  └─ Length low: 0x07 (7 bytes)
│  │  └─ Length high: 00
│  └─ Opcode: 07 (HELLO)
└─ Start: AA
```
- Byte 4: `PROTOCOL_VERSION` (currently `0x01`)
- Byte 5: app version length (here `0x05`)
- Bytes 6+: app version string ("0.2.3")
- Firmware replies with `0x86 DEVICE_TELEMETRY`.

### Events (Device → App)

#### Keep Alive Reply (0x81)
```
aa 81 00 00
```

#### Profile Changed (0x82)
```
aa 82 00 01 02
```
- Byte 4: New profile index (0-based)

#### Button Pressed (0x83)
```
aa 83 00 04 00 03 43 4f 4e
```
- Byte 4: Profile index (0-based)
- Byte 5: Button name length
- Bytes 6+: Button name ("CON")

#### Key Pressed (0x84)
```
aa 84 00 02 00 41
```
- Byte 4: Profile index (0-based)
- Byte 5: Key character ASCII (0x41 = 'A')

#### Battery Status (0x85)
```
aa 85 00 01 48    (72% battery)
aa 85 00 01 ff    (no battery / USB-only)
```
- Byte 4: Battery percentage `0–100`, or `0xFF` when no LiPo cell is detected
- Sent automatically ~every 30 s while a host is connected

#### Device Telemetry (0x86)
Reply to `HELLO`. Carries protocol version, firmware version, and runtime stats.
```
aa 86 00 12 01 05 31 2e 32 2e 33 00 00 13 88 01 00 03 0d 40 00 00
│  │  │  │  │  │  └──┴──┴──┴──┘  └──┴──┴──┴──┘ │  └──┴──┴──┴──┘ └──┘
│  │  │  │  │  │  "1.2.3"        uptime=5000ms │  free_heap     ble_errors=0
│  │  │  │  │  │                  (0x00001388) │  =200000 bytes (uint16 BE)
│  │  │  │  │  │                               │  (0x00030D40)
│  │  │  │  │  │                               └─ reset_reason: 1 (POWERON)
│  │  │  │  │  └─ Firmware version length: 5
│  │  │  │  └─ Protocol version: 1
│  │  │  └─ Length low: 0x12 (18 bytes)
│  │  └─ Length high: 00
│  └─ Opcode: 86 (DEVICE_TELEMETRY)
└─ Start: AA
```
- Byte 4: protocol_version (compare against host)
- Byte 5: firmware version length
- Bytes 6..10: firmware version ("1.2.3")
- Bytes 11..14: uptime_ms big-endian uint32
- Byte 15: reset_reason (`0`=unknown, `1`=POWERON, `3`=software, `5`=deep-sleep wake, `6`=brownout, `8`=task WDT, `9`=interrupt WDT)
- Bytes 16..19: free_heap big-endian uint32 (bytes available)
- Bytes 20..21: ble_error_count big-endian uint16 (cumulative since boot — spike ⇒ radio drift / version mismatch)

## Debugging in the Windows App

The Windows app logs all packets in hex format:

### Outgoing Packets
Look for lines like:
```
→ aa03000e020104...
```
This is the hex data being sent to the device.

### Incoming Packets
Look for lines like:
```
← aa82000102
```
This is the hex data received from the device.

### Decode a Log Entry

1. Copy the hex string from the log
2. Run the decoder:
   ```bash
   python protocol_decoder.py aa82000102
   ```

3. Output:
   ```
   PACKET ANALYSIS
   ================
   Raw hex: aa82000102
   Length: 5 bytes

   HEADER:
     Start Byte: 0xAA ✓
     Opcode:     0x82 - PROFILE_CHANGED
     Length:     1 bytes (0x0001)

   PAYLOAD (1 bytes):
     Hex: 02
     Bytes: 02

   DECODED PAYLOAD:
     ➤ Profile Changed (Device Event)
       New Profile Index: 2 (0-based)
   ```

## Common Issues

### Profile Sync Not Working

**Symptom**: Device doesn't show correct profile names

**Debug**:
1. Look for the sync packet in the log: `→ aa03...`
2. Decode it with the decoder
3. Verify:
   - Count matches number of profiles
   - Each profile has correct index (1-based)
   - Names are correctly encoded

**Expected packet for 2 profiles**:
```
aa 03 00 0e 02 01 07 50726f66696c65 02 09 50726f66696c6532
         │  │  │  │                │  │  │
         │  │  │  └─ "Profile"     │  │  └─ "Profile2"
         │  │  └─ length=7         │  └─ length=9
         │  └─ index=1             └─ index=2
         └─ count=2
```

### RGB Colors Not Updating

**Symptom**: LEDs don't change color

**Debug**:
1. Check for RGB packet: `→ aa05...` (all keys) or `→ aa04...` (single key)
2. Decode to verify colors
3. For Set All RGB Keys:
   - Packet should be exactly 68 bytes (4 header + 64 payload)
   - Each key should have 4 bytes (RGBW)

### Profile Changes Not Detected

**Symptom**: App doesn't sync when device profile changes

**Debug**:
1. Look for incoming packets: `← aa82...`
2. Decode to see the profile index
3. Verify the index is 0-based (0, 1, 2, not 1, 2, 3)
4. Check if profile index is within app's profile range

## Testing Protocol Encoding

Run the protocol unit tests to verify encoding:

```bash
pytest windows_app/tests/test_ble_protocol.py -v
```

This will:
- Encode test packets via the real builders
- Parse them back through `BLEPacket.parse`
- Verify correctness against the spec

## Manual Packet Creation

You can manually create packets for testing:

```python
import ble_protocol

# Create a keep-alive packet
packet = ble_protocol.keep_alive()
print(packet.hex())  # aa010000

# Create a sync profiles packet
profiles = {1: "Test", 2: "Default"}
packet = ble_protocol.sync_profiles(profiles)
print(packet.hex())

# Parse an incoming packet
data = bytes.fromhex("aa82000102")
opcode, payload = ble_protocol.BLEPacket.parse(data)
profile_idx = ble_protocol.parse_profile_changed(payload)
print(f"Profile changed to: {profile_idx}")
```

## Arduino Serial Debug Output

The Arduino firmware logs protocol operations to Serial:

```
RX <- Opcode: 0x03, Length: 14
Syncing 2 profiles
Synced profile 1: 'Test'
Synced profile 2: 'Default'
```

Match these with the app logs to verify communication.

## Troubleshooting Checklist

- [ ] START_BYTE is always 0xAA
- [ ] Opcode matches expected command/event
- [ ] LENGTH field matches actual payload size
- [ ] Profile indices are 1-based in commands, 0-based in events
- [ ] Strings are UTF-8 encoded with length prefix
- [ ] RGB values are in range 0-255
- [ ] All multi-byte values are big-endian
- [ ] Packet fits within protocol limit (max payload 256 bytes)

## Example Debugging Session

**Problem**: Profiles not syncing to device

**Step 1**: Check app log for sync packet
```
📁 Synchronizing 2 profiles to device...
  Profile 1: 'My Profile'
  Profile 2: 'Gaming'
  Packet size: 32 bytes
→ aa03001c020109...
```

**Step 2**: Decode the packet
```bash
python protocol_decoder.py aa03001c020109...
```

**Step 3**: Verify output
- Count = 2 ✓
- Profile 1: index=1, name="My Profile" ✓
- Profile 2: index=2, name="Gaming" ✓

**Step 4**: Check Arduino serial output
```
RX <- Opcode: 0x03, Length: 28
Syncing 2 profiles
Synced profile 1: 'My Profile'
Synced profile 2: 'Gaming'
```

✓ **Resolution**: Protocol is working correctly, profiles synced successfully.

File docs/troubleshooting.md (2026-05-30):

# BLEDeck — Troubleshooting

Common failures and how to diagnose them. Check the rows top-to-bottom; the
"First check" column usually resolves the issue.

## Connection

| Symptom | First check | Then check | Last resort |
|---|---|---|---|
| App stays *Disconnected* forever | Bluetooth adapter enabled in Windows Settings? | Device powered, OLED on? | Remove the device from Windows Bluetooth pairing list, then reconnect from the app |
| App connects then drops within seconds | BLE adapter supports BLE 4.0+? | Other Bluetooth peripherals interfering? | Move device closer (<3 m); check `bledeck.log` under `%APPDATA%\BLEDeck\logs\` |
| Multiple BLEDecks in range, wrong one connects | App settings now pin the first MAC address used. Delete `%APPDATA%\BLEDeck\app_settings.json` to reset, then reconnect to the desired device first | — | — |
| `[SIMULATOR]` shown in window title | `BLEDECK_SIM=1` environment variable is set | Unset it (`set BLEDECK_SIM=` on cmd, `Remove-Item Env:BLEDECK_SIM` on PowerShell) and restart the app | Reboot if env var persists |

> The app now prints these checks under the *Debug Log* (Help → Enable Debug)
> as a `❌ Device not found` block — flip the panel on if you're triaging
> a no-connect report.

## Battery

| Symptom | First check | Then check | Last resort |
|---|---|---|---|
| Battery shows 100 % when pack is half drained | Plug USB, watch the `[BAT] adc=... vbat=... pct=...` serial line | Compare `vbat` against a multimeter on the battery terminals | Reflash with `pio run -e calibrate -t upload` and follow the printed retune formula |
| Battery shows `USB` when battery is connected | ADC reads `0 mV` → check divider wiring | Confirm `BAT_PIN` (GPIO 13) is connected to the divider mid-tap | Try a different ADC1 pin in `configuration.h` (ADC2 has known quirks on ESP32) |

## OTA

| Symptom | First check | Then check | Last resort |
|---|---|---|---|
| OTA web page says *Auth failed* | `OTA_HTTP_PASSWORD` in `credentials.h` matches what the browser sent | Browser cached a stale password — open a private window | Reflash via USB (`pio run -t upload`) and reset the password |
| OTA endpoint stops accepting uploads | Five wrong-password attempts within 60 s trigger a 5-minute lockout — wait it out | Watch serial for `[OTA] Auth lockout` | Power-cycle the device |
| Device can't join WiFi | `OTA_WIFI_SSID` / `OTA_WIFI_PASSWORD` in `credentials.h` match the AP | 2.4 GHz network? The ESP32 does not do 5 GHz | Use the AP fallback (`BLEDeck-OTA`) — random password is on the OLED |
| Build error: undefined `OTA_HTTP_PASSWORD` | Open `credentials.h` and rename the old `OTA_PASSWORD` macro to `OTA_HTTP_PASSWORD` | See `firmware/src/credentials.h.example` | Copy the example file fresh: `cp src/credentials.h.example src/credentials.h` |

## Profiles & macros

| Symptom | First check | Then check | Last resort |
|---|---|---|---|
| Profile file disappeared | Check `%APPDATA%\BLEDeck\profiles.json.corrupt.json` — the app renames bad files instead of overwriting | History snapshots under `%APPDATA%\BLEDeck\history\` (most recent first) | Use File → New, recreate; see `bledeck.log` for the failure reason |
| Macro fires into the wrong window | The recorder picked the wrong anchor. Open the macro editor and inspect each `ClickStep`'s `relative_to` — `window:<title>` vs `monitor:<n>` vs `abs` | Re-record while the target window is the foreground app | Set the anchor manually to `monitor:<n>` for desktop/taskbar clicks |
| Profile name truncated on the device OLED | App UI is now capped at 39 chars; older files may exceed. Edit the name in Edit mode and save | — | Hand-edit `profiles.json` and trim to 39 UTF-8 bytes |
| App pops "untrusted commands" warning on load | The profile file contains commands flagged as risky (`powershell`, `cmd /c`, `curl ... | iex`, etc.). Inspect and either remove or confirm trust per profile file | — | Edit the JSON to remove the risky command |

## Logs

Rotating log lives at `%APPDATA%\BLEDeck\logs\bledeck.log` (5 × 20 MB rotation, 100 MB cap). `KEEP_ALIVE` traffic is filtered out to keep it readable. Open it in any editor for chronological app activity.

## Asking for help

Open an issue at the project's GitHub. Include:
1. App version (Help → Info), firmware version (visible on device OLED for ~2 s at boot, or in `[BAT]` serial line context).
2. The most recent ~200 lines of `bledeck.log`.
3. Output of `pio device monitor` for the same timeframe if firmware is involved.
4. Steps to reproduce.

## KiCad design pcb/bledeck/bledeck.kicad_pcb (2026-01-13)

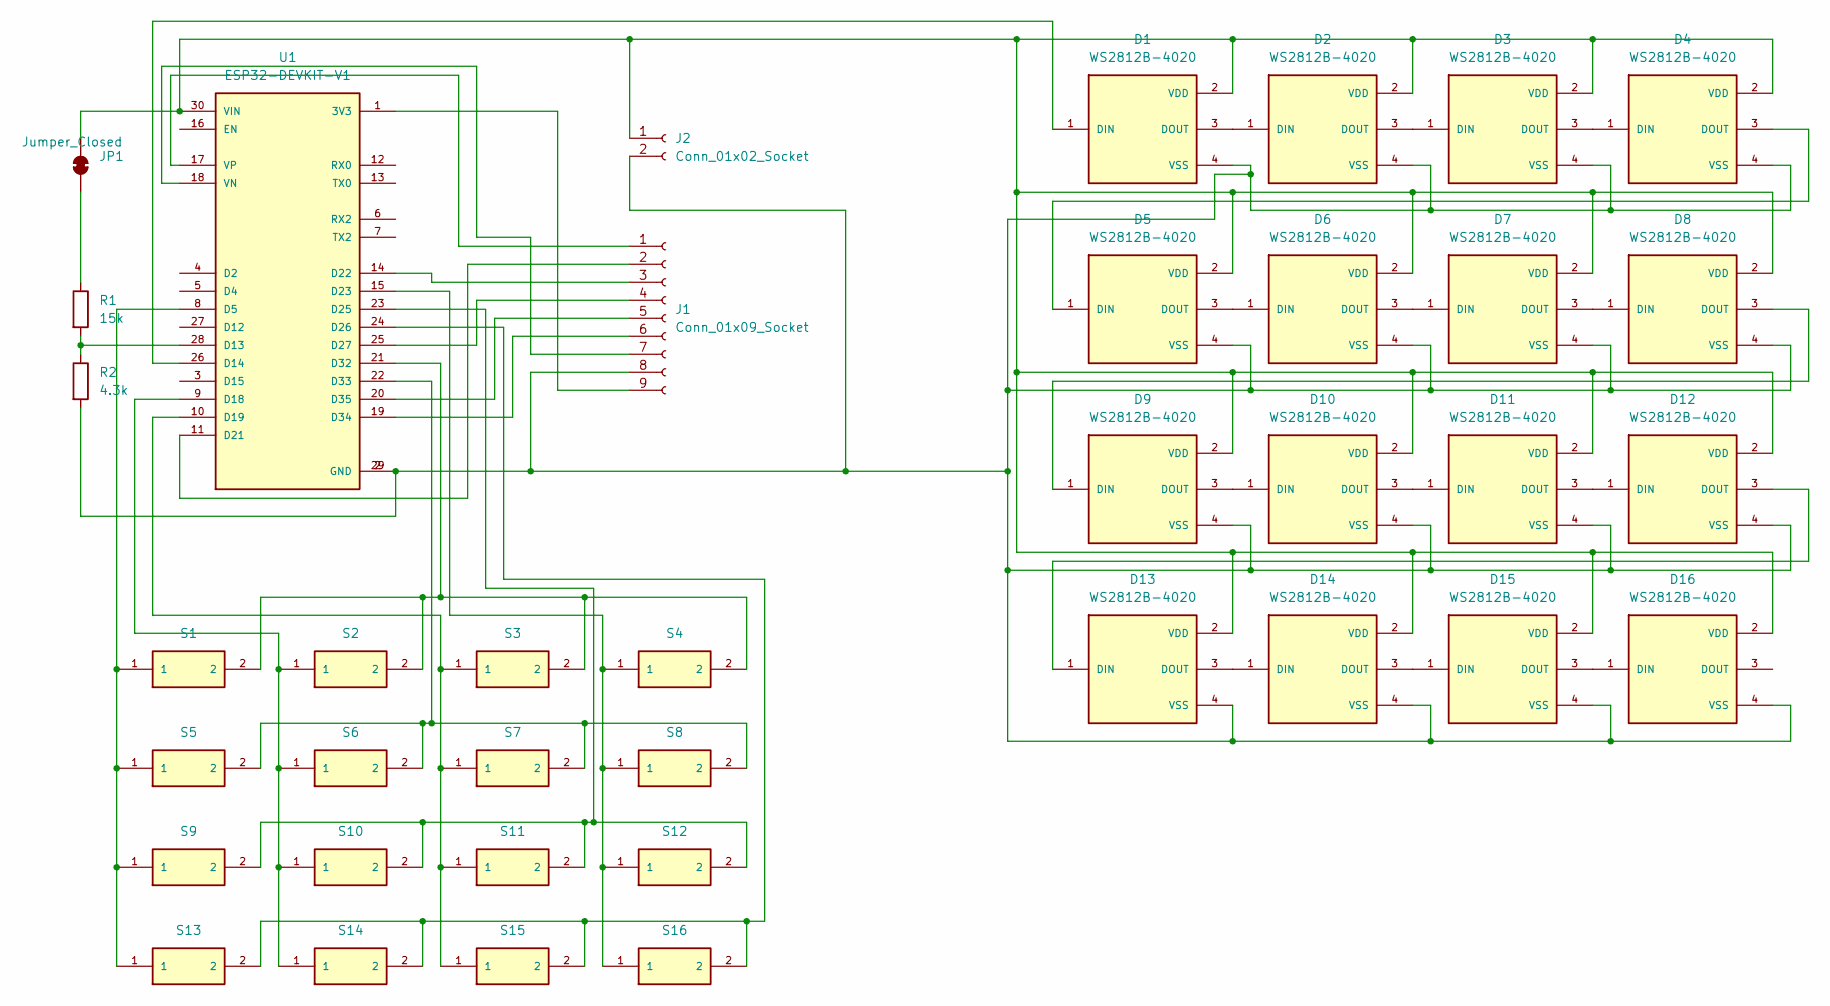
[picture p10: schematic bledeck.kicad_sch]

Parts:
D1, D2, D3, D4, D5, D6, D7, D8, D9, D10, D11, D12, D13, D14, D15, D16: WS2812B-4020; PARTREV V1.2
J1: Conn_01x09_Socket; oled_rotary
J2: Conn_01x02_Socket; PinHeader_1x02_P2.54mm_Vertical
JP1: Jumper_Closed; PinHeader_1x02_P2.54mm_Vertical
R1: 15k; R_Axial_DIN0207_L6.3mm_D2.5mm_P7.62mm_Horizontal
R2: 4.3k; R_Axial_DIN0207_L6.3mm_D2.5mm_P7.62mm_Horizontal
S1, S2, S3, S4, S5, S6, S7, S8, S9, S10, S11, S12, S13, S14, S15, S16: PG151101S11; SW_PG151101S11; PARTREV A
U1: ESP32-DEVKIT-V1; MODULE_ESP32_DEVKIT_V1; PARTREV N/A

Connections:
unnamed: D1.1 (DIN), U1.26 (D14)
unnamed: D1.3 (DOUT), D2.1 (DIN)
unnamed: D1.2 (VDD), D2.2 (VDD), D3.2 (VDD), D4.2 (VDD), D5.2 (VDD), D6.2 (VDD), D7.2 (VDD), D8.2 (VDD), D9.2 (VDD), D10.2 (VDD), D11.2 (VDD), D12.2 (VDD), D13.2 (VDD), D14.2 (VDD), D15.2 (VDD), D16.2 (VDD), J2.1, JP1.2 (B), U1.30 (VIN)
unnamed: D1.4 (VSS), D2.4 (VSS), D3.4 (VSS), D4.4 (VSS), D5.4 (VSS), D6.4 (VSS), D7.4 (VSS), D8.4 (VSS), D9.4 (VSS), D10.4 (VSS), D11.4 (VSS), D12.4 (VSS), D13.4 (VSS), D14.4 (VSS), D15.4 (VSS), D16.4 (VSS), J1.8, J2.2, R2.2, U1.2 (GND), U1.29 (GND)
unnamed: D2.3 (DOUT), D3.1 (DIN)
unnamed: D3.3 (DOUT), D4.1 (DIN)
unnamed: D4.3 (DOUT), D5.1 (DIN)
unnamed: D5.3 (DOUT), D6.1 (DIN)
unnamed: D6.3 (DOUT), D7.1 (DIN)
unnamed: D7.3 (DOUT), D8.1 (DIN)
unnamed: D8.3 (DOUT), D9.1 (DIN)
unnamed: D9.3 (DOUT), D10.1 (DIN)
unnamed: D10.3 (DOUT), D11.1 (DIN)
unnamed: D11.3 (DOUT), D12.1 (DIN)
unnamed: D12.3 (DOUT), D13.1 (DIN)
unnamed: D13.3 (DOUT), D14.1 (DIN)
unnamed: D14.3 (DOUT), D15.1 (DIN)
unnamed: D15.3 (DOUT), D16.1 (DIN)
unnamed: J1.1, U1.17 (VP)
unnamed: J1.2, U1.11 (D21)
unnamed: J1.3, U1.14 (D22)
unnamed: J1.4, U1.25 (D27)
unnamed: J1.5, U1.20 (D35)
unnamed: J1.6, U1.19 (D34)
unnamed: J1.7, U1.18 (VN)
unnamed: J1.9, U1.1 (3V3)
unnamed: JP1.1 (A), R1.1
unnamed: S1.1, S5.1, S9.1, S13.1, U1.8 (D5)
unnamed: R1.2, R2.1, U1.28 (D13)
unnamed: S2.1, S6.1, S10.1, S14.1, U1.9 (D18)
unnamed: S3.1, S7.1, S11.1, S15.1, U1.10 (D19)
unnamed: S4.1, S8.1, S12.1, S16.1, U1.15 (D23)
unnamed: S9.2, S10.2, S11.2, S12.2, U1.23 (D25)
unnamed: S13.2, S14.2, S15.2, S16.2, U1.24 (D26)
unnamed: S1.2, S2.2, S3.2, S4.2, U1.21 (D32)
unnamed: S5.2, S6.2, S7.2, S8.2, U1.22 (D33)

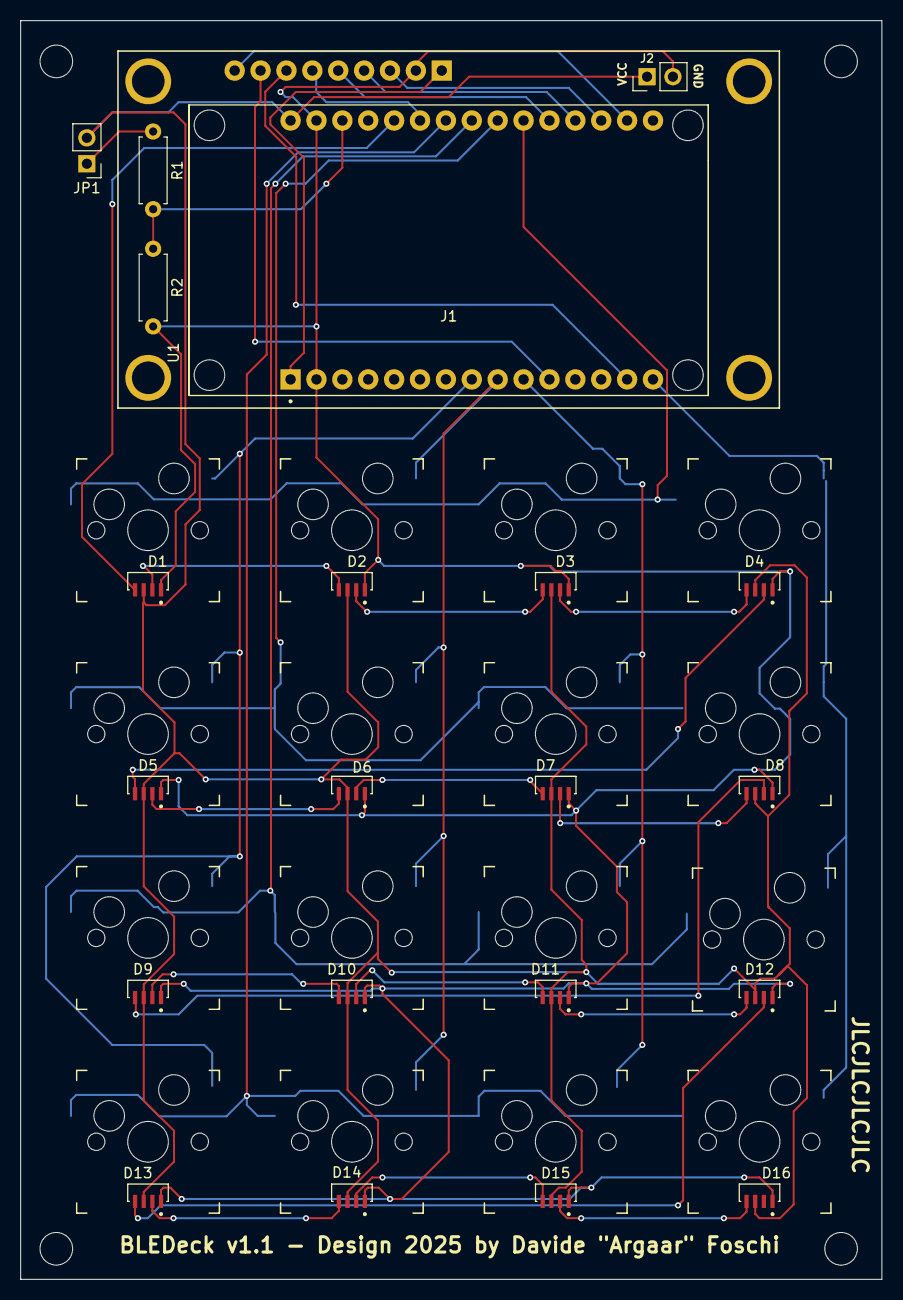
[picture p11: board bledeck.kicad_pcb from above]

Board: 2 copper layers, 84.5 x 123.5 mm, 38 parts (0 on the bottom side), 36 nets.

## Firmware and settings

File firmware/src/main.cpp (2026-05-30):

#include "configuration.h"
#include "protocolparser.h"
#include "menu.h"
#include "ota_manager.h"
#include "version.h"
#include <esp_system.h>
#include <images.h>

#include <Keypad.h>

#include <ESP32RotaryEncoder.h>
#include <Bounce2.h>

#include <Wire.h>
#include "SSD1306Wire.h"
#include "OLEDDisplay.h"

#include <BLEDevice.h>
#include <BLEServer.h>
#include <BLEUtils.h>
#include <BLE2902.h>
#include <BLESecurity.h>

#include <NeoPixelBus.h>

#ifdef USE_BATTERY
#include "CircularBuffer.hpp"
#endif

#include <vector>

// Protocol Parser
ProtocolParser parser;

// Profiles - can be updated from Windows app
int currentProfile = 0;
const int MAX_PROFILES = 10;  // Support up to 10 profiles
String profileNames[MAX_PROFILES] = {"Default"};  // Initialize first profile, rest will be set by app
int profileCount = 1;  // Track number of profiles received from app

// BLE Connection Management
BLEServer* pServer;
BLECharacteristic* pTxCharacteristic;
bool deviceConnected = false;
bool oldDeviceConnected = false;
unsigned long lastPingTime = 0;
unsigned long connectionStartTime = 0;

// BATTERY PROPERTIES
#ifdef USE_BATTERY
static uint32_t last_read_bat = 0;
CircularBuffer<float, BAT_NUM_READ> bat_readings;
int batteryLevel = 0;
#endif

// Misc
bool workstationLocked = false;
unsigned long lastColorShift = 0;

// Counts BLE-side errors (parse failures, malformed payloads, send aborts).
// Surfaced via OP_DEVICE_TELEMETRY so the app can flag a flaky link.
uint16_t bleErrorCount = 0;

// Menu & OTA state
SimpleMenu* activeMenu = nullptr;
OtaManager* otaManager = nullptr;
bool otaActive = false;

// Packed RGB + brightness (W = 0..100 %) — 4 bytes per key.
// Replaces an earlier String-based representation that caused heap
// fragmentation on long uptime (every per-key update reallocated four
// temporary String objects).
struct RGBW {
  uint8_t r;
  uint8_t g;
  uint8_t b;
  uint8_t w;
};

// OLED
SSD1306Wire * display;

void oledUpdate() {
  display->clear();

  display->setFont(ArialMT_Plain_16);
  display->drawString(0, 0, "Current profile:");

  display->setFont(ArialMT_Plain_24);
  display->drawString(0, 18, profileNames[currentProfile]);

  char dev_status[40];
  #ifdef USE_BATTERY
  snprintf(dev_status, sizeof(dev_status), "BT: %s | Bat: %d%%", deviceConnected ? "CONN" : "DISCONN", batteryLevel);
  #else
  snprintf(dev_status, sizeof(dev_status), "BT: %s", deviceConnected ? "CONN" : "DISCONN");
  #endif
  display->setFont(ArialMT_Plain_10);
  display->drawString(0, 50, dev_status);

  display->display();
}

void oledUpdateLockedStatus() {
  if (workstationLocked) {
    display->clear();
    display->drawXbm((display->getWidth()-LOCK_IMAGE_WIDTH)/2, (display->getHeight()-LOCK_IMAGE_HEIGHT)/2, LOCK_IMAGE_WIDTH, LOCK_IMAGE_HEIGHT, LOCK_IMAGE);
    display->display();
  } else {
    oledUpdate();
  }
}

// BLE Send Helpers
void sendBinaryPacket(uint8_t opcode, const uint8_t* payload, uint16_t payloadLen) {
  if (!deviceConnected) {
    Serial.println("Cannot send - device not connected");
    bleErrorCount++;
    return;
  }

  if (!pTxCharacteristic) {
    Serial.println("Cannot send - characteristic not available");
    bleErrorCount++;
    return;
  }

  if (payloadLen > MAX_BLE_PAYLOAD_LEN) {
    Serial.printf("Error: payload too large (%d)\n", payloadLen);
    bleErrorCount++;
    return;
  }

  // Build packet: START + OPCODE + LENGTH(2B) + PAYLOAD
  uint8_t packet[4 + MAX_BLE_PAYLOAD_LEN];
  packet[0] = START_BYTE;
  packet[1] = opcode;
  packet[2] = (payloadLen >> 8) & 0xFF;  // Length high byte
  packet[3] = payloadLen & 0xFF;          // Length low byte

  if (payloadLen > 0 && payload != nullptr) {
    memcpy(packet + 4, payload, payloadLen);
  }

  pTxCharacteristic->setValue(packet, 4 + payloadLen);
  pTxCharacteristic->notify();
  #ifdef DEBUG_SERIAL
  Serial.printf("TX -> Opcode: 0x%02X, Length: %d\n", opcode, payloadLen);
  #endif
}

void sendKeepAliveReply() {
  sendBinaryPacket(OP_KEEP_ALIVE_REPLY, nullptr, 0);
  lastPingTime = millis();
}

void sendProfileChanged(uint8_t profileIndex) {
  if (workstationLocked) {
    #ifdef DEBUG_SERIAL
    Serial.println("Workstation Locked - no actions allowed");
    #endif
    return;
  }
  sendBinaryPacket(OP_PROFILE_CHANGED, &profileIndex, 1);
}

void sendButtonPressed(const char* buttonName) {
  if (workstationLocked) {
    #ifdef DEBUG_SERIAL
    Serial.println("Workstation Locked - no actions allowed");
    #endif
    return;
  }

  // Payload: profile_index(1B) + button_name_length(1B) + button_name
  uint8_t nameLen = (uint8_t)min((size_t)MAX_BUTTON_NAME_LEN, strlen(buttonName));
  uint8_t payload[2 + MAX_BUTTON_NAME_LEN];
  payload[0] = currentProfile;
  payload[1] = nameLen;
  memcpy(payload + 2, buttonName, nameLen);

  sendBinaryPacket(OP_BUTTON_PRESSED, payload, 2 + nameLen);
}

void sendKeyPressed(char key) {
  if (workstationLocked) {
    #ifdef DEBUG_SERIAL
    Serial.println("Workstation Locked - no actions allowed");
    #endif
    return;
  }

  // Payload: profile_index(1B) + key(1B)
  uint8_t payload[2];
  payload[0] = currentProfile;
  payload[1] = (uint8_t)key;

  sendBinaryPacket(OP_KEY_PRESSED, payload, 2);
}

void sendDeviceTelemetry() {
  if (!deviceConnected) return;
  const char* fw_ver = FIRMWARE_VERSION;  // from version.h
  uint8_t fw_len = (uint8_t)strlen(fw_ver);
  uint32_t uptime_ms = millis();
  uint8_t reset_reason = (uint8_t)esp_reset_reason();
  uint32_t free_heap = ESP.getFreeHeap();
  uint16_t err_count = bleErrorCount;

  uint8_t payload[1 + 1 + 64 + 4 + 1 + 4 + 2];
  size_t off = 0;
  payload[off++] = PROTOCOL_VERSION;
  payload[off++] = fw_len;
  if (fw_len > 64) fw_len = 64;
  memcpy(payload + off, fw_ver, fw_len);
  off += fw_len;
  payload[off++] = (uptime_ms >> 24) & 0xFF;
  payload[off++] = (uptime_ms >> 16) & 0xFF;
  payload[off++] = (uptime_ms >>  8) & 0xFF;
  payload[off++] = (uptime_ms      ) & 0xFF;
  payload[off++] = reset_reason;
  payload[off++] = (free_heap >> 24) & 0xFF;
  payload[off++] = (free_heap >> 16) & 0xFF;
  payload[off++] = (free_heap >>  8) & 0xFF;
  payload[off++] = (free_heap      ) & 0xFF;
  payload[off++] = (err_count >> 8) & 0xFF;
  payload[off++] = (err_count     ) & 0xFF;

  sendBinaryPacket(OP_DEVICE_TELEMETRY, payload, off);
}

// BATTERY MGMT
#ifdef USE_BATTERY
void sendBatteryStatus() {
  // 0xFF signals "no battery / USB-only" to the app
  uint8_t pct = (batteryLevel == 999) ? 0xFF : (uint8_t)batteryLevel;
  sendBinaryPacket(OP_BATTERY_STATUS, &pct, 1);
}

void batteryLoop(){
    if (0 == last_read_bat || millis() - last_read_bat > BAT_INTERVAL_MS) {

        uint16_t v = analogReadMilliVolts(BAT_PIN);
        if (v!=0) {
            bat_readings.push(v);
            float bat_values = 0.0;
            for (int i = 0; i < bat_readings.size(); ++i) {
                bat_values = bat_values + bat_readings[i];
            }
            float avg_adc_mv = bat_values / bat_readings.size();
            float avg_bat_voltage = avg_adc_mv * ( (BAT_R1 + BAT_R2) / BAT_R2 ) * BAT_CALIBRATION;
            float percent = (avg_bat_voltage - BAT_MIN_V) * 100.0 / (BAT_MAX_V - BAT_MIN_V);

            // Clamp between 0% and 100%
            if (percent < 0) percent = 0;
            if (percent > 100) percent = 100;
            // Always log raw + computed values so the divider can be calibrated.
            // Compare printed Vbat against a multimeter reading; if off, adjust
            // BAT_R1 / BAT_R2 / BAT_CALIBRATION in configuration.h.
            Serial.printf("[BAT] adc=%.0fmV vbat=%.0fmV pct=%.0f\n",
                          avg_adc_mv, avg_bat_voltage, percent);
            #ifdef CALIBRATE_BATTERY
            // Guided calibration build (pio run -e calibrate). Probe the
            // battery terminals with a multimeter and feed the reading into
            // the formula below; paste the result into configuration.h.
            float theoretical_mult = (BAT_R1 + BAT_R2) / BAT_R2;
            Serial.printf(
                "[CALIBRATE] current BAT_CALIBRATION=%.4f, theoretical_mult=%.4f\n"
                "[CALIBRATE] new BAT_CALIBRATION = multimeter_mV / (%.0f * %.4f)\n"
                "[CALIBRATE] e.g. if multimeter reads 4035 mV -> %.4f\n",
                (float)BAT_CALIBRATION, theoretical_mult,
                avg_adc_mv, theoretical_mult,
                4035.0f / (avg_adc_mv * theoretical_mult));
            #endif
            batteryLevel = int(percent);
        } else {
            #ifdef DEBUG_SERIAL
            Serial.println("No battery!");
            #endif
            batteryLevel = 999;
        }
        last_read_bat = millis();
        oledUpdate();
        if (deviceConnected) {
            sendBatteryStatus();
        }
    }
}
#endif

// RGB
NeoPixelBus<NeoGrbFeature, NeoWs2812xMethod> rgb_keys(RGB_NUM, RGB_PIN);

const RGBW defaultRgbColors[RGB_NUM] = {
  {255,   0,   0, 80},
  {255,  96,   0, 80},
  {255, 191,   0, 80},
  {255, 255,   0, 80},
  {191, 255,   0, 80},
  { 96, 255,   0, 80},
  {  0, 255,   0, 80},
  {  0, 255,  96, 80},
  {  0, 255, 191, 80},
  {  0, 191, 255, 80},
  {  0,  96, 255, 80},
  {  0,   0, 255, 80},
  { 96,   0, 255, 80},
  {191,   0, 255, 80},
  {255,   0, 191, 80},
  {255,   0,  96, 80}
};

RGBW rgbColors[RGB_NUM];

// WS2812B refresh limiter: bursts of per-key updates coalesce into ~60 Hz
// strip writes. Faster than the eye can resolve, frees ~7.7 ms per dropped
// Show() call during slider drags / fast colour edits.
static bool     rgbShowPending_ = false;
static uint32_t rgbLastShowMs_  = 0;
constexpr uint32_t kRgbMinFrameIntervalMs = 16;

void resetRgbColors() {
  memcpy(rgbColors, defaultRgbColors, sizeof(rgbColors));
}

void rgbUpdateColors(const RGBW* colorArray, int idx = -1) {
  if (idx < 0) { // negative idx means update in bulk
    for (size_t i = 0; i < RGB_NUM; i++) {
      RgbColor color = RgbColor(colorArray[i].r, colorArray[i].g, colorArray[i].b);
      rgb_keys.SetPixelColor(i, color.Dim(map(colorArray[i].w, 0, 100, 0, 255)));
    }
  } else {
    RgbColor color = RgbColor(colorArray[idx].r, colorArray[idx].g, colorArray[idx].b);
    rgb_keys.SetPixelColor(idx, color.Dim(map(colorArray[idx].w, 0, 100, 0, 255)));
  }
  // Defer the actual Show() to rgbFlush() so back-to-back updates coalesce.
  rgbShowPending_ = true;
}

// Pump the deferred-refresh state machine. Call from loop() every tick.
// No-op if nothing changed or the limiter window has not elapsed.
void rgbFlush() {
  if (!rgbShowPending_) return;
  uint32_t now = millis();
  if (now - rgbLastShowMs_ < kRgbMinFrameIntervalMs) return;
  rgb_keys.Show();
  rgbLastShowMs_ = now;
  rgbShowPending_ = false;
}

void rotateColors(RGBW* colors, size_t count) {
  if (count < 2) return;

  RGBW first = colors[0];
  for (size_t i = 1; i < count; i++) {
    colors[i - 1] = colors[i];
  }
  colors[count - 1] = first;
}

// Handlers
void handlePacket(const ParsedPacket &pkt) {
  #ifdef DEBUG_SERIAL
  Serial.printf("RX <- Opcode: 0x%02X, Length: %d\n", pkt.opcode, pkt.length);
  #endif

  // Reset ping timer on any received message
  lastPingTime = millis();

  switch (pkt.opcode) {
    case OP_KEEP_ALIVE: {
      // Keep alive ping - send reply
      sendKeepAliveReply();
      break;
    }

    case OP_CHANGE_PROFILE: {
      // Payload: profile_index(1B) + name_length(1B) + name
      if (pkt.length < 2) {
        Serial.println("Error: CHANGE_PROFILE packet too short");
        bleErrorCount++;
        break;
      }

      uint8_t profileIndex = pkt.payload[0];
      uint8_t nameLength = pkt.payload[1];

      if (pkt.length < 2 + nameLength) {
        Serial.println("Error: CHANGE_PROFILE packet incomplete");
        bleErrorCount++;
        break;
      }

      // Extract profile name
      String profileName = "";
      for (int i = 0; i < nameLength; i++) {
        profileName += (char)pkt.payload[2 + i];
      }

      // Store profile name (profile index is 1-based on the wire)
      if (profileIndex == 0 || profileIndex > MAX_PROFILES) {
        Serial.printf("Error: Invalid profile index %d\n", profileIndex);
        bleErrorCount++;
        break;
      }
      int idx = profileIndex - 1;
      profileNames[idx] = profileName;
      if (idx >= profileCount) {
        profileCount = idx + 1;
      }
      currentProfile = idx;
      oledUpdate();
      #ifdef DEBUG_SERIAL
      Serial.printf("Applied CHANGE_PROFILE -> %d (%s)\n", idx, profileNames[idx].c_str());
      #endif
      break;
    }

    case OP_SYNC_PROFILES: {
      // Payload: count(1B) + [index(1B) + name_len(1B) + name]*count
      if (pkt.length < 1) {
        Serial.println("Error: SYNC_PROFILES packet too short");
        bleErrorCount++;
        break;
      }

      uint8_t count = pkt.payload[0];
      #ifdef DEBUG_SERIAL
      Serial.printf("Syncing %d profiles\n", count);
      #endif

      int offset = 1;
      for (int i = 0; i < count; i++) {
        if (offset + 2 > pkt.length) break;

        uint8_t profileIndex = pkt.payload[offset++];
        uint8_t nameLen = pkt.payload[offset++];

        if (offset + nameLen > pkt.length) break;

        String name = "";
        for (int j = 0; j < nameLen; j++) {
          name += (char)pkt.payload[offset++];
        }

        // Store profile name (1-based on the wire; index 0 reserved)
        if (profileIndex == 0 || profileIndex > MAX_PROFILES) {
          Serial.printf("SYNC: bad profile index %d, aborting\n", profileIndex);
          bleErrorCount++;
          break;
        }
        int idx = profileIndex - 1;
        profileNames[idx] = name;
        if (idx >= profileCount) {
          profileCount = idx + 1;
        }
        #ifdef DEBUG_SERIAL
        Serial.printf("Synced profile %d: '%s'\n", profileIndex, name.c_str());
        #endif
      }

      // Update display with current profile
      oledUpdate();
      break;
    }

    case OP_SET_RGB_KEY: {
      // Payload: key_index(1B) + R(1B) + G(1B) + B(1B) + W(1B)
      if (pkt.length != 5) {
        Serial.println("Error: SET_RGB_KEY invalid length");
        bleErrorCount++;
        break;
      }

      uint8_t keyIndex = pkt.payload[0];
      uint8_t r = pkt.payload[1];
      uint8_t g = pkt.payload[2];
      uint8_t b = pkt.payload[3];
      uint8_t w = pkt.payload[4];

      // Validate indices
      if (keyIndex >= RGB_NUM) {
        Serial.printf("Error: Invalid key index %d\n", keyIndex);
        bleErrorCount++;
        break;
      }

      // Update the color for this key
      rgbColors[keyIndex] = {r, g, b, w};

      #ifdef DEBUG_SERIAL
      Serial.printf("Set key %d to RGBW(%d,%d,%d,%d)\n", keyIndex, r, g, b, w);
      #endif

      // Update the LED immediately
      rgbUpdateColors(rgbColors, keyIndex);
      break;
    }

    case OP_SET_ALL_RGB_KEYS: {
      // Payload: 16 x RGBW (64 bytes total)
      if (pkt.length != 64) {
        Serial.printf("Error: SET_ALL_RGB_KEYS invalid length (expected 64, got %d)\n", pkt.length);
        bleErrorCount++;
        break;
      }

      #ifdef DEBUG_SERIAL
      Serial.println("Setting all 16 RGB keys");
      #endif

      // Update all 16 keys
      for (size_t i = 0; i < RGB_NUM; i++) {
        rgbColors[i] = {
          pkt.payload[i * 4],
          pkt.payload[i * 4 + 1],
          pkt.payload[i * 4 + 2],
          pkt.payload[i * 4 + 3]
        };
      }

      // Update all LEDs at once
      rgbUpdateColors(rgbColors);
      #ifdef DEBUG_SERIAL
      Serial.println("All RGB keys updated");
      #endif
      break;
    }

    case OP_LOCK_DEVICE: {
      // Payload: lock_flag(1B) - 0x01=lock, 0x00=unlock
      if (pkt.length != 1) {
        Serial.println("Error: LOCK_DEVICE invalid length");
        bleErrorCount++;
        break;
      }

      uint8_t lockFlag = pkt.payload[0];

      if (lockFlag == 0x01) {
        workstationLocked = true;
        display->setBrightness(50);
        oledUpdateLockedStatus();
        #ifdef DEBUG_SERIAL
        Serial.println("Device LOCKED");
        #endif
      } else if (lockFlag == 0x00) {
        workstationLocked = false;
        display->setBrightness(255);
        oledUpdate();
        #ifdef DEBUG_SERIAL
        Serial.println("Device UNLOCKED");
        #endif
      } else {
        Serial.printf("Error: Invalid lock flag 0x%02X\n", lockFlag);
        bleErrorCount++;
      }
      break;
    }
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
void loop() {
  // Always update buttons so menu and long-press work regardless of BLE state
  btn_encoder_con.update();
  btn_encoder_back.update();
  btn_encoder_push.update();

  // OTA mode: hand off entirely to OTA manager
  if (otaActive) {
    // BACK cancels OTA - but never interrupt an in-progress upload.
    // Require ≥1000 ms hold (release with long duration) to avoid accidental cancel.
    if (btn_encoder_back.released() &&
        btn_encoder_back.previousDuration() >= 1000 &&
        !otaManager->isUpdating()) {
      #ifdef DEBUG_SERIAL
      Serial.println("OTA cancelled by user");
      #endif
      delete otaManager;
      otaManager = nullptr;
      otaActive = false;
      ESP.restart();
      return;
    }
    otaManager->loop();
    // Timeout only fires when idle (not mid-upload)
    if (otaManager->timedOut() && !otaManager->isUpdating()) {
      delete otaManager;
      otaManager = nullptr;
      otaActive = false;
      #ifdef DEBUG_SERIAL
      Serial.println("OTA timeout - restarting");
      #endif
      ESP.restart();
    }
    delay(10);
    return;
  }

  // Menu mode: handle navigation and selection
  if (activeMenu != nullptr) {
    handleMenuInput();
    delay(10);
    return;
  }

  // Long press PUSH (>MENU_LONG_PRESS_MS) opens settings menu
  if (!workstationLocked &&
      btn_encoder_push.released() &&
      btn_encoder_push.previousDuration() > MENU_LONG_PRESS_MS) {
    openMenu();
    return;
  }

  // Handle connection state changes
  if (!deviceConnected && oldDeviceConnected) {
    delay(500); // Give the bluetooth stack time to clean up
    oldDeviceConnected = deviceConnected;
    #ifdef DEBUG_SERIAL
    Serial.println("Connection cleanup completed");
    #endif
  }

  // Debug: Log connection status changes
  static bool lastConnectedState = false;
  if (deviceConnected != lastConnectedState) {
    #ifdef DEBUG_SERIAL
    Serial.printf("Connection state changed: %s\n", deviceConnected ? "CONNECTED" : "DISCONNECTED");
    #endif
    lastConnectedState = deviceConnected;
  }

  // Connection timeout check - disconnect if app stops pinging
  if (deviceConnected && (millis() - lastPingTime > BLE_PING_TIMEOUT_MS)) {
    #ifdef DEBUG_SERIAL
    Serial.println("Connection timeout - no ping received");
    #endif
    pServer->disconnect(pServer->getConnId());
    // Defensive: ensure cleanup branch runs even if onDisconnect callback misfires
    deviceConnected = false;
    oldDeviceConnected = true;
  }

  if (deviceConnected) {
    if (btn_encoder_con.pressed()){
      #ifdef DEBUG_SERIAL
      Serial.println("CON PRESSED");
      #endif
      sendButtonPressed("CON");
    }

    if (btn_encoder_back.pressed()){
      #ifdef DEBUG_SERIAL
      Serial.println("BACK PRESSED");
      #endif
      sendButtonPressed("BACK");
    }

    // Short PUSH release sends event; long press was already handled above
    if (btn_encoder_push.released() &&
        btn_encoder_push.previousDuration() <= MENU_LONG_PRESS_MS) {
      #ifdef DEBUG_SERIAL
      Serial.println("PUSH PRESSED");
      #endif
      sendButtonPressed("PUSH");
    }

    // Read keypad input
    char key = keypad->getKey();
    if (key && !workstationLocked) {
      #ifdef DEBUG_SERIAL
      Serial.println(key);
      #endif
      sendKeyPressed(key);
    }

    // Perform encoder action — but never rotate profiles while locked.
    if (workstationLocked) {
      turnedRightFlag = false;
      turnedLeftFlag = false;
    } else if (turnedRightFlag) {
      turnedRightFlag = false;
      #ifdef DEBUG_SERIAL
      Serial.println("Right ->");
      #endif
      currentProfile++;
      if (currentProfile >= profileCount) {
        currentProfile = 0;  // Wrap to first profile
      }
      handleProfileChange();
    } else if (turnedLeftFlag) {
      turnedLeftFlag = false;
      #ifdef DEBUG_SERIAL
      Serial.println("<- Left");
      #endif
      currentProfile--;
      if (currentProfile < 0) {
        currentProfile = profileCount - 1;  // Wrap to last profile
      }
      handleProfileChange();
    }
  } else {
    // Play idle RGB animation when not connected.
    // Note: rgbUpdateColors() now defers the strip write — rgbFlush() below
    // performs the actual Show() within the same loop iteration.
    if (millis() - lastColorShift >= 200) {   // 200 ms passed
      lastColorShift = millis();
      rotateColors(rgbColors, RGB_NUM);
      rgbUpdateColors(rgbColors);
    }
  }

  // Coalesce any pending WS2812B updates into a single ~60 Hz refresh.
  rgbFlush();

  #ifdef USE_BATTERY
  // Update adc reading
  batteryLoop();
  #endif

  // Active path: yield to the BLE host task without sleeping. Drops keypress→
  // dispatch latency from ~10 ms worst case to ~1 ms. Disconnected path keeps
  // the longer delay as a power-save (idle RGB animation only needs ~5 Hz).
  if (deviceConnected) {
    vTaskDelay(1);
  } else {
    delay(10);
  }
}

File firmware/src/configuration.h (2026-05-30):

#ifndef CONFIGURATION_H
#define CONFIGURATION_H

// #define DEBUG_SERIAL  // Uncomment for verbose serial logging

// OLED
#define SCREEN_WIDTH            128
#define SCREEN_HEIGHT           64
#define I2C_SDA                 21
#define I2C_SCL                 22
#define SSD1306_ADDRESS         0x3C

// Encoder
#define DI_ENCODER_A            GPIO_NUM_35
#define DI_ENCODER_B            GPIO_NUM_34
#define DI_ENCODER_CON          GPIO_NUM_36
#define DI_ENCODER_BACK         GPIO_NUM_39
#define DI_ENCODER_PUSH         GPIO_NUM_27
#define BUTTON_DEBOUNCE_MS      50

// Keys
#define ROW_PIN_1               GPIO_NUM_32
#define ROW_PIN_2               GPIO_NUM_33
#define ROW_PIN_3               GPIO_NUM_25
#define ROW_PIN_4               GPIO_NUM_26
#define COL_PIN_1               GPIO_NUM_5
#define COL_PIN_2               GPIO_NUM_18
#define COL_PIN_3               GPIO_NUM_19
#define COL_PIN_4               GPIO_NUM_23

// RGB
#define RGB_PIN                 GPIO_NUM_14
#define RGB_NUM                 16

// BLE packet limits - must match ParsedPacket::payload size in protocolparser.h
#define MAX_BLE_PAYLOAD_LEN  256
#define MAX_BUTTON_NAME_LEN  32

// BLE connection health
// Drop connection if no KEEP_ALIVE received within this window. App pings
// every 10s, so 30s tolerates up to two consecutive missed pings.
#define BLE_PING_TIMEOUT_MS  30000UL

// OTA Update
#include "credentials.h"   // gitignored - copy credentials.h.example and fill in
#define OTA_HOSTNAME            "bledeck"
#define OTA_AP_SSID             "BLEDeck-OTA"   // AP fallback network name
#define OTA_AP_PASSWORD_LEN     12              // random AP password length
#define OTA_TIMEOUT_MS          300000UL    // 5 minutes
#define MENU_LONG_PRESS_MS      1500         // ms to hold PUSH to open menu

// Power Management
#define USE_BATTERY
#define BAT_INTERVAL_MS         (30 * 1000)     // Battery sample interval (milliseconds)
#ifdef CALIBRATE_BATTERY
#undef BAT_INTERVAL_MS
#define BAT_INTERVAL_MS         (5 * 1000)      // Faster sampling in calibration build (pio run -e calibrate)
#endif
// 1S LiPo divider on GPIO 13: PCB ships with R1=15k (top, to BAT+), R2=4.3k (bottom, to GND).
// Empirical calibration (best-fit through origin across two measurements):
//   adc=2427 mV → multimeter 3948 mV
//   adc=2505 mV → multimeter 4035 mV
// Best-fit effective Vbat/Vadc multiplier = 1.6185. The theoretical divider
// multiplier (R1+R2)/R2 = 4.488, so BAT_CALIBRATION ≈ 1.6185 / 4.488 = 0.3607.
// The over-read is likely caused by ADC2 behaviour on GPIO 13 combined with
// internal attenuation calibration; do not change the resistor constants to
// compensate — keep them matching the soldered board.
// Watch the `[BAT] adc=... vbat=... pct=...` serial line and compare vbat
// against a multimeter; tune BAT_CALIBRATION to match.
#define BAT_R1                  15000.0         // top resistor (to VIN)
#define BAT_R2                  4300.0          // bottom resistor (to GND)
#define BAT_CALIBRATION         0.3607          // empirical ADC correction (1.000 = no correction)
#define BAT_NUM_READ            5
#define BAT_MAX_V               4200            // Max voltage of a 1S LiPo cell (in mV)
#define BAT_MIN_V               3200            // Min useful voltage of a 1S LiPo cell (in mV); 3700 showed 0% at ~15% remaining
#define BAT_PIN                 GPIO_NUM_13

#endif // CONFIGURATION_H

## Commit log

2025-10-28 change display, fix key label
    [configuration.h]
2025-11-10 add pcb
    [bledeck.kicad_pcb, bledeck.kicad_sch, configuration.h]
2025-11-11 generate gerber, fix pin number
    [BOM-bledeck.csv, bledeck.kicad_pcb, bledeck.kicad_sch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]
2025-11-11 pcb add libraries and readme with licenses
    [bledeck.kicad_pcb, bledeck.kicad_sch]
2025-11-13 add missing file from previous commit
    [main.cpp]
2025-11-20 switch ble protocol to binary format, add docs to document protocol, add debug scripts to test protocol data, fix some issues in both app and firmware
    [custom_partitions.csv]
2025-11-20 remove prefs, fix rgb key in code and docs, remove profile+rgb payload when switching, remove unused code, small improvements in firmware
    [main.cpp]
2025-11-20 fix locked state, add rgb animation when idle
    [main.cpp]
2025-11-24 fix bug in single rgb sync, add pynput as dependecy in order to support macro inputs, update dependecies, fix protocol_decoder
    [main.cpp]
2025-11-27 [firmware] add battery info [pcb] evenly spaced keys, fix oled pins position, reroute all tracks/vias, add gerber zip for jlcpcb
    [BOM-bledeck.csv, bledeck.kicad_pcb, bledeck.kicad_sch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]
2025-12-16 [firmware] add battery to display, fix oledupdate [pcb] fix keys connections, fix led traces, fix oled footprint [misc] add parts list to Readme
    [bledeck.kicad_pcb, bledeck.kicad_sch, configuration.h]
2025-12-18 [firmware] fix battery mgmt
    [configuration.h]
2025-12-18 [firmware] add ifdef for adc attenuation
2026-01-13 [pcb] version 1.1 [firmware] enabled 16 rgb, change keys layout
    [bledeck.kicad_pcb, bledeck.kicad_sch, configuration.h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]
2026-03-12 upload stl files for 3d print encloure
    [BatteryLayer.stl, BatteryTop.stl, Bottom.stl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]
2026-04-29 add readme for each subproject, add general readme, add battery report via bt to app, add ota support with elegant ota, change partition layout to free up some space add wifi support to flash new fir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
    [configuration.h, partitions_ota.csv]
2026-04-29 fix stls
    [BatteryLayer.stl, BatteryTop.stl, Bottom.stl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]
2026-04-29 fix in some Readme files
    [configuration.h]
2026-05-05 fix keyboard stl
2026-05-07 create per folder gitignore files, decrease hole size for keyboardlayer stl
2026-05-30 [common] add open-source meta, simulator, firmware tests, app hardening
    Project meta:
    - add LICENSE, CONTRIBUTING.md, CHANGELOG.md, PR template, pyproject.toml
    - add run-tests.sh/.bat, docs/troubleshooting.md
    [simulator] new component: in-process FakeBleakClient loopback (Mode A) +
    WinRT GATT server (Mode B), CLI REPL, command_handler/event_emitter
    sharing ble_protocol.py, full pytest suite
    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
    [configuration.h]
2026-05-30 [misc] add CI test workflow [docs] add 3D renders to README
    [misc] .github/workflows/tests.yml — runs firmware native (Unity) on
    ubuntu and the Python suites (windows_app + simulator) on windows.
    Triggers: manual dispatch (with all/firmware/python selector), push to
    main, and pull_request.
    [docs] README: embed assets/3d_renders images (front, side, keys, hot-swap
    connectors) and add a Tests workflow status badge.
2026-05-30 [misc] add Windows app build workflow on release
    .github/workflows/build-windows.yml — runs windows_app/build.bat
    (PyInstaller via bledeck.spec) on windows-latest. On a published GitHub
    release, zips dist/BLEDeck/ and attaches it as a release asset; on manual
    dispatch, uploads the zip as a run artifact only.
2026-05-30 [misc] silence CI Node 20 warning and windows-latest redirect notice
    - Drop the optional PlatformIO cache step (actions/cache@v4 has no Node 24
    major and still warns even when forced); native build is fast without it.
    Removes the now-unneeded FORCE_JAVASCRIPT_ACTIONS_TO_NODE24 env.
    - Pin Windows jobs to windows-2025 (windows-latest is being redirected to
    windows-2025-vs2026 by June 2026).
2026-05-30 [misc] fix credential leak in personalized firmware workflow
    workflow_dispatch inputs are not auto-masked, and the runner prints each
    step's env: block in plaintext at step start — so defining the inputs as
    job-level env exposed WiFi/OTA credentials in the logs (public on a public
    repo). Read the inputs from $GITHUB_EVENT_PATH at runtime, ::add-mask::
    them, and re-export via $GITHUB_ENV instead. No env: key carries the
    secrets anymore.
